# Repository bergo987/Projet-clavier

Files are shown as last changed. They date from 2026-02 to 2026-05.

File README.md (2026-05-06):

# Clavier mécanique programmable – Projet EEL8-PROJ1 [CLA]

## 📌 Présentation du projet

Ce dépôt contient le travail réalisé dans le cadre du **projet thématique EEL8-PROJ1 (2025–2026)** à l’ENSEIRB-MATMECA.  
L’objectif du projet est de **concevoir et réaliser un clavier mécanique programmable** basé sur un **microcontrôleur**, communiquant avec un ordinateur via le standard **USB HID**.

Contrairement aux solutions existantes « clé en main » (ex. QMK), ce projet privilégie le **développement d’un firmware personnalisé**, afin de maîtriser les aspects bas niveau du système embarqué. Nous avons programmé la carte Raspberry Pi pico directement (en baremetal).

---

## 🎯 Objectifs

- Concevoir un **clavier mécanique compact et minimaliste** ✅
- Implémenter un **scan matriciel des touches** ✅
- Gérer le **n-key rollover** et l’**anti-ghosting**
- Développer un **firmware bas niveau** sur microcontrôleur ✅
- Communiquer avec un ordinateur via **USB HID** ✅
- Ajouter une **interface utilisateur** :
  - LEDs sous les touches ✅
  - Gestion de profils ✅
  - Écran OLED pour l’affichage du profil actif et de la mesure de courant ✅ 🚧

---

## 🧠 Fonctionnalités principales

- Lecture matricielle des touches
- Détection fiable des appuis multiples
- Gestion de plusieurs profils clavier
- Éclairage LED configurable selon le profil
- Affichage des informations sur écran OLED
- Communication USB HID avec l’ordinateur

---

## 🛠️ Technologies utilisées

- **Microcontrôleur** : Raspberry Pi Pico (RP2040) [git ici](https://github.com/raspberrypi/pico-sdk)
- **Langage** : C / C++ (firmware embarqué)
- **Communication** : USB HID
- **Conception électronique** : PCB personnalisé
- **Interface utilisateur** :
  - LEDs adressables
  - Écran OLED
  - Potentiomètre (Seul le bouton fonctionne)

---

## 🧩 Organisation du projet

```text
├── firmware/        # Code source du firmware
├── hardware/        # Fichiers 3D et fichiers sources KIKAD
├── docs/            # Documentation technique
├── images/          # Illustrations et photos du projet
└── README.md
```

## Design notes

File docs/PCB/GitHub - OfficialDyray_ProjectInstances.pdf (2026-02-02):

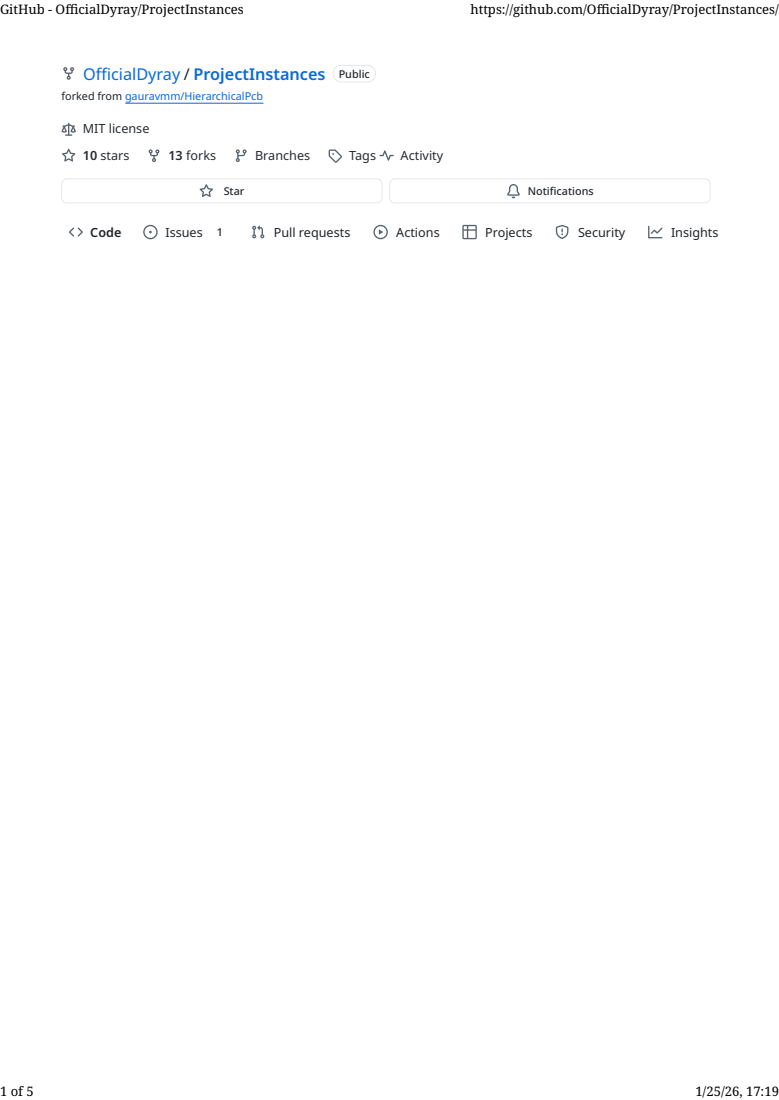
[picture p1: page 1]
10 stars; 13 forks; Branches; Tags; Activity; Star; Notifications; Code; Issues; Pull requests; Actions; Projects; Security; Insights; GitHub - OfficialDyray/ProjectInstances; https://github.com/OfficialDyray/ProjectInstances/

OfficialDyray (https://github.com/OfficialDyray) / ProjectInstances (https://github.com/OfficialDyray/ProjectInstances) Public
forked from gauravmm/HierarchicalPcb (https://github.com/gauravmm/HierarchicalPcb)
MIT license (https://github.com/OfficialDyray/ProjectInstances/blob/schParser/LICENSE)

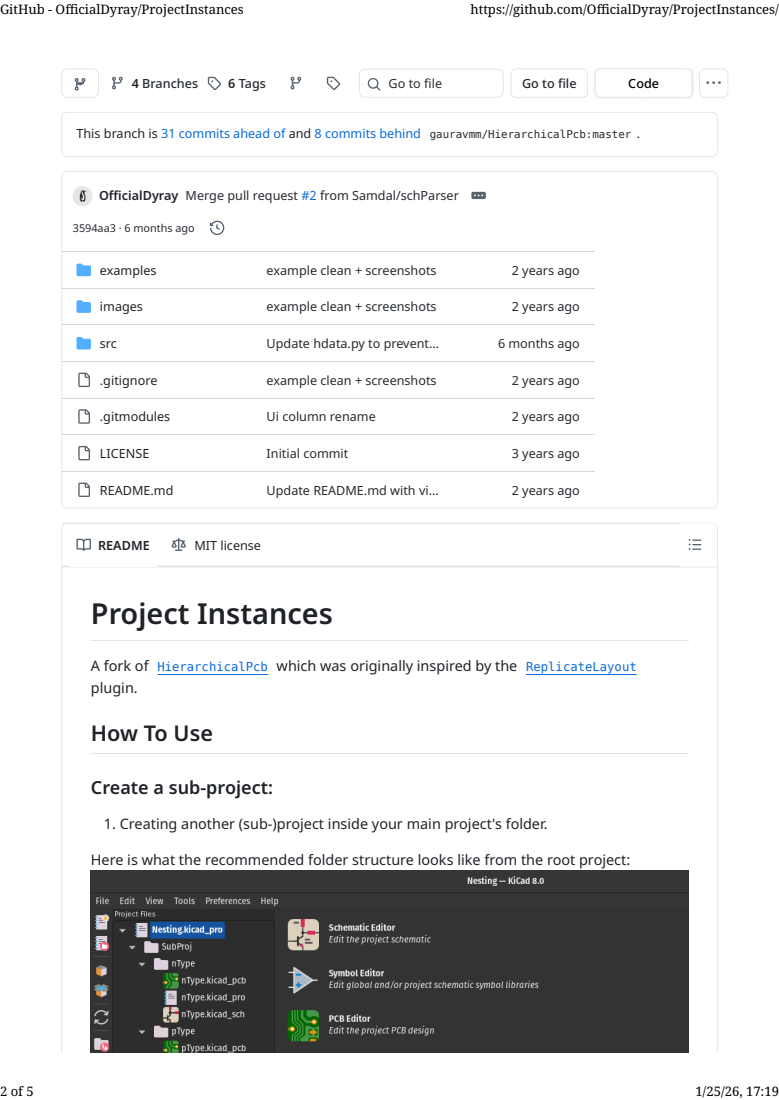
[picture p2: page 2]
4 Branches; 6 Tags; Go to file; Code; This branch is 31 commits ahead of and 8 commits behind; gauravmm/HierarchicalPcb:master; 3594aa3 · 6 months ago; examples; example clean + screenshots; 2 years ago; images; src; Update hdata.py to prevent…; 6 months ago; .gitignore; .gitmodules; Ui column rename; LICENSE; Initial commit; 3 years ago; README.md; Update README.md with vi…; A fork of; HierarchicalPcb; which was originally inspired by the; ReplicateLayout; plugin.; Project Instances; README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

OfficialDyray (https://github.com/OfficialDyray/ProjectInstances/commits?author=OfficialDyray) Merge pull request (https://github.com/OfficialDyray/ProjectInstances/commit/3594aa3a2f53df845697bdb446bcac1a703b43f1) #2 (https://github.com/OfficialDyray/ProjectInstances/pull/2) from Samdal/schParser

How To Use

Create a sub-project:
1. Creating another (sub-)project inside your main project's folder.
Here is what the recommended folder structure looks like from the root project:

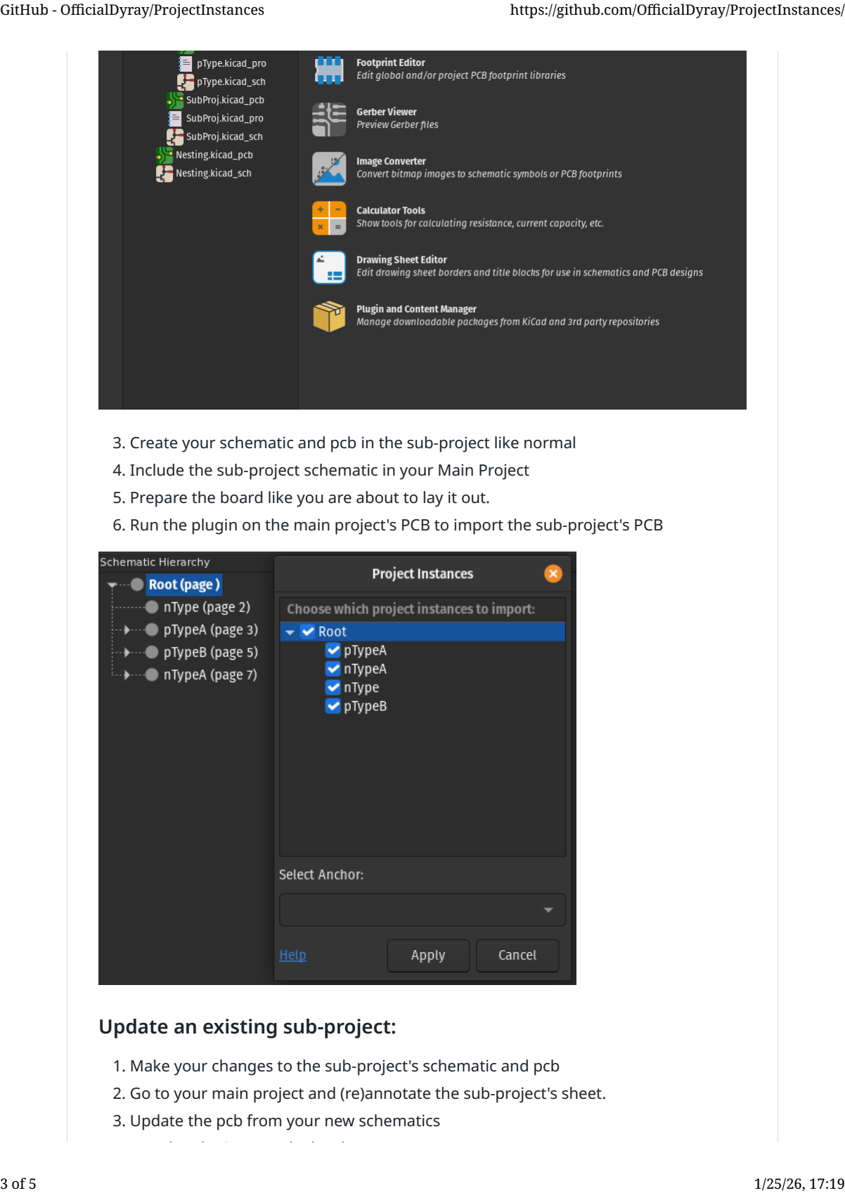
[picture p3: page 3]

3. Create your schematic and pcb in the sub-project like normal
4. Include the sub-project schematic in your Main Project
5. Prepare the board like you are about to lay it out.
6. Run the plugin on the main project's PCB to import the sub-project's PCB
1. Make your changes to the sub-project's schematic and pcb
2. Go to your main project and (re)annotate the sub-project's sheet.
3. Update the pcb from your new schematics

Update an existing sub-project:

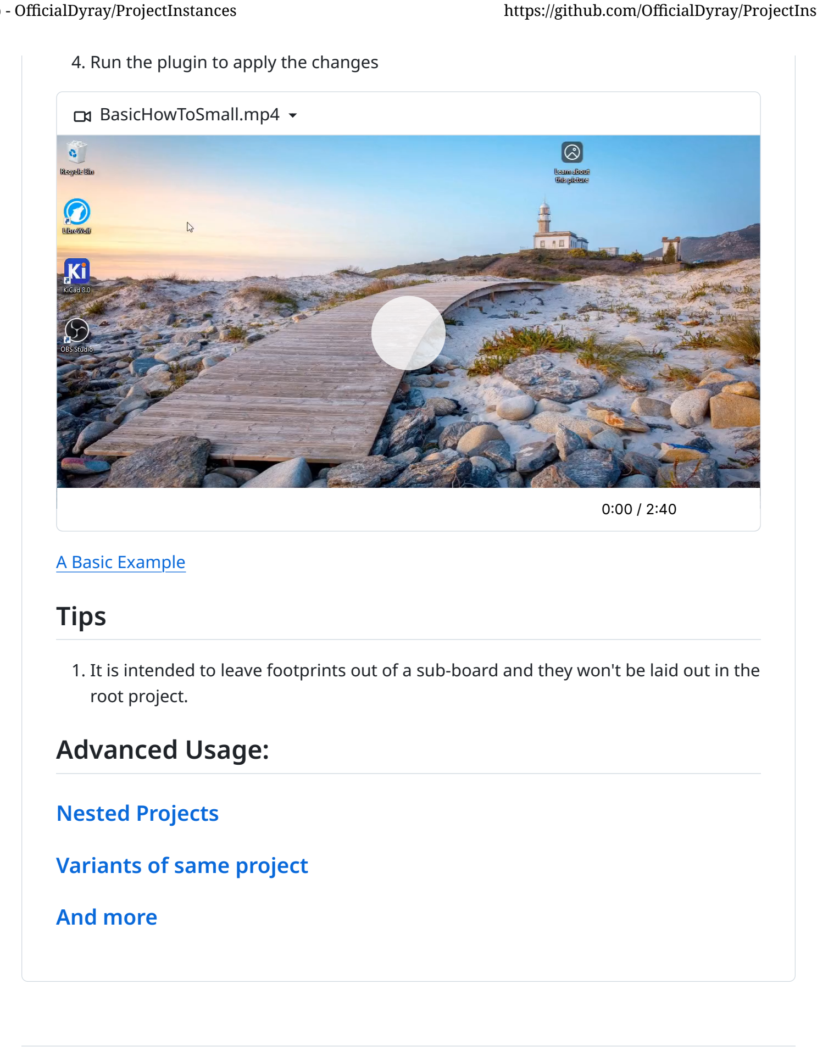
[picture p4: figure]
4. Run the plugin to apply the changes; BasicHowToSmall.mp4; A Basic Example; root project.; Tips; Advanced Usage:; Nested Projects; Variants of same project; And more

1. It is intended to leave footprints out of a sub-board and they won't be laid out in the

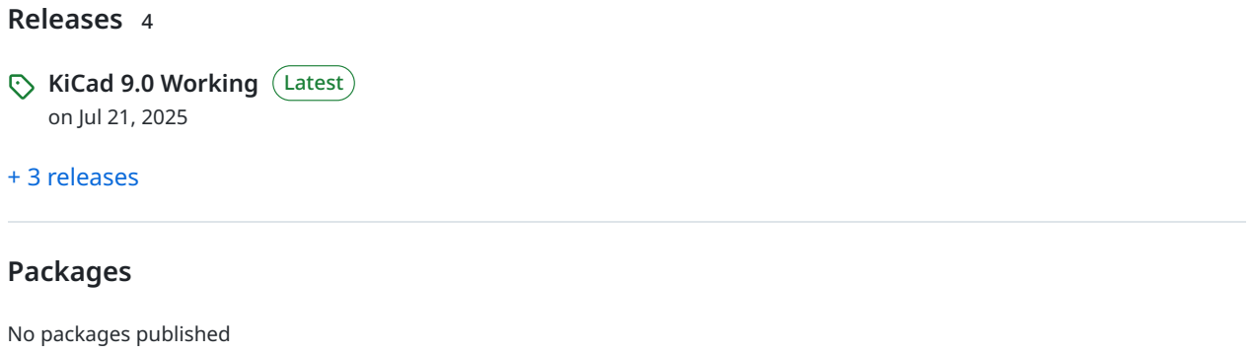
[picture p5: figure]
Releases; KiCad 9.0 Working Latest on Jul 21, 2025; + 3 releases; Packages; No packages published

Languages

Python 100.0%

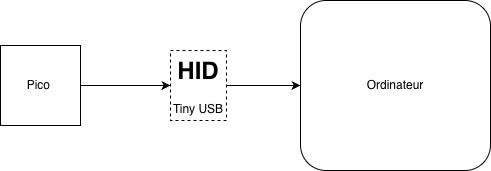
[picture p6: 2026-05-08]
firmware/Hid.png

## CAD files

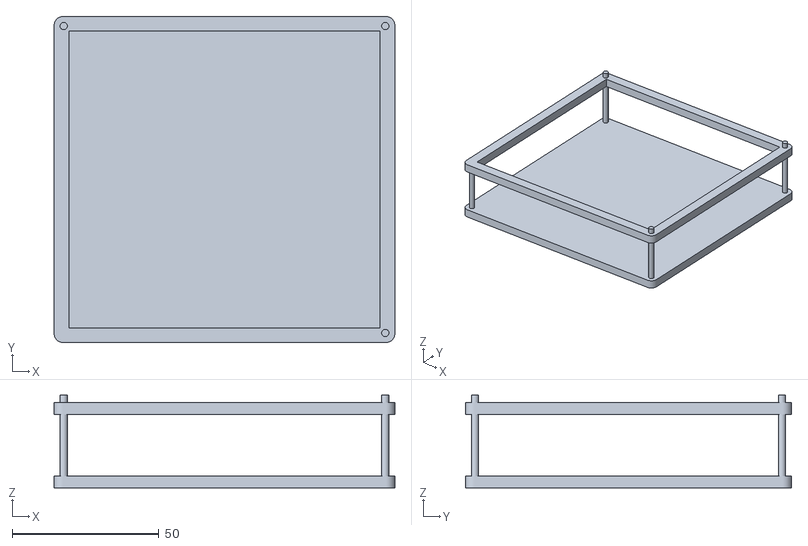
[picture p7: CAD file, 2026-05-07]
hardware/Case.stl
116.0 x 111.0 x 31.5

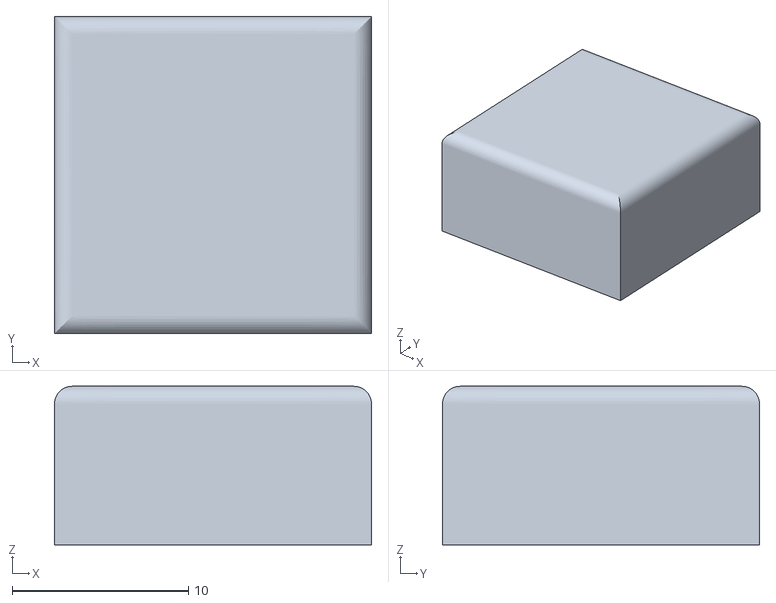
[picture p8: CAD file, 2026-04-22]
hardware/Keycap.stl
18.0 x 18.0 x 9.00

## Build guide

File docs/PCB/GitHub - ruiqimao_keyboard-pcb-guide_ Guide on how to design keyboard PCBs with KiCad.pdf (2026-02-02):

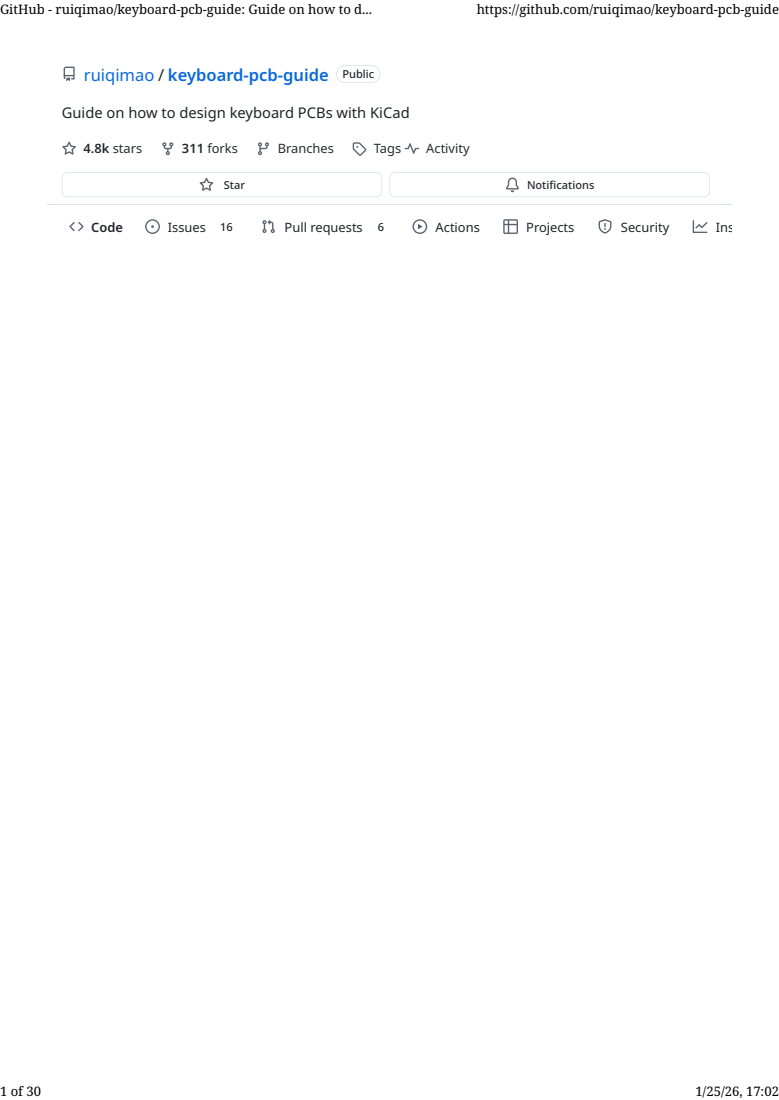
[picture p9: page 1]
4.8k stars; 311 forks; Branches; Tags; Activity; Star; Notifications; Code; Issues; Pull requests; Actions; Projects; Security; Insights; GitHub - ruiqimao/keyboard-pcb-guide: Guide on how to d...; https://github.com/ruiqimao/keyboard-pcb-guide

ruiqimao (https://github.com/ruiqimao) / keyboard-pcb-guide (https://github.com/ruiqimao/keyboard-pcb-guide) Public

Guide on how to design keyboard PCBs with KiCad

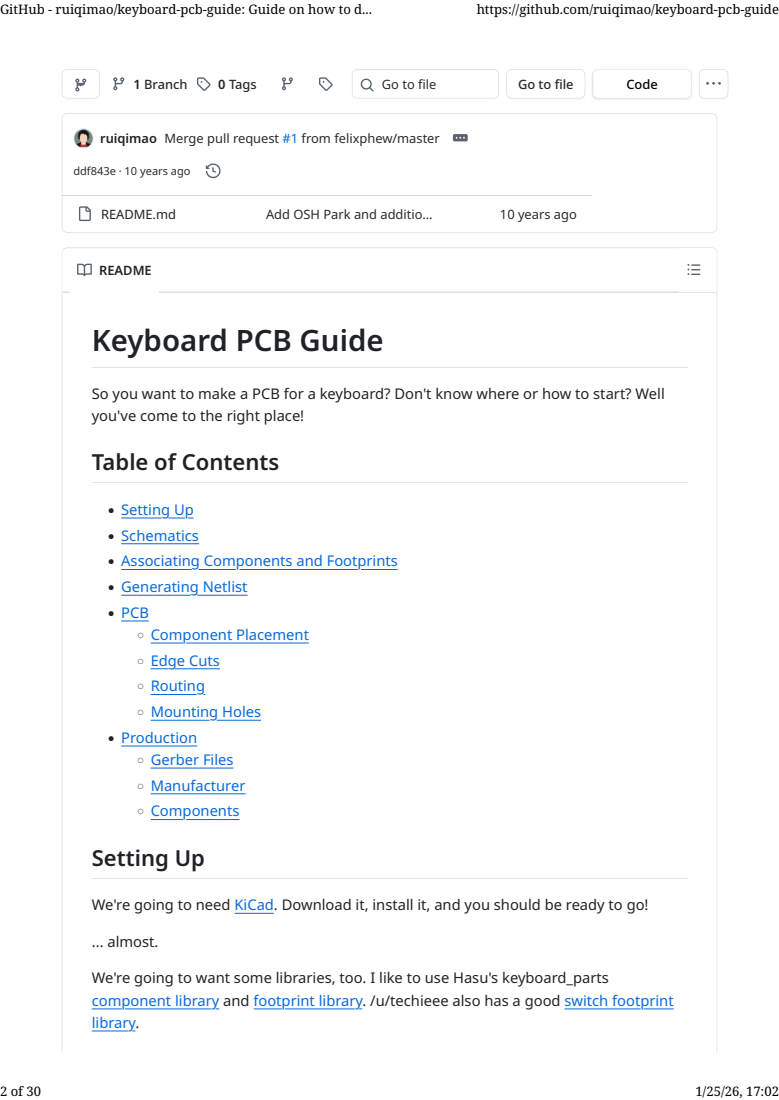
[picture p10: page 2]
1 Branch; 0 Tags; Go to file; Code; ddf843e · 10 years ago; README.md; Add OSH Park and additio…; 10 years ago; Setting Up; README

ruiqimao (https://github.com/ruiqimao/keyboard-pcb-guide/commits?author=ruiqimao) Merge pull request (https://github.com/ruiqimao/keyboard-pcb-guide/commit/ddf843ee5a5d36edd875370d22974dc7cd6f62e4) #1 (https://github.com/ruiqimao/keyboard-pcb-guide/pull/1) from felixphew/master

Keyboard PCB Guide

So you want to make a PCB for a keyboard? Don't know where or how to start? Well
you've come to the right place!

Table of Contents

• Setting Up (https://github.com/ruiqimao/keyboard-pcb-guide#setting-up)
• Schematics (https://github.com/ruiqimao/keyboard-pcb-guide#schematics)
• Associating Components and Footprints (https://github.com/ruiqimao/keyboard-pcb-guide#associating-components-and-footprints)
• Generating Netlist (https://github.com/ruiqimao/keyboard-pcb-guide#generating-netlist)
• PCB (https://github.com/ruiqimao/keyboard-pcb-guide#pcb)
◦ Component Placement (https://github.com/ruiqimao/keyboard-pcb-guide#component-placement)
◦ Edge Cuts (https://github.com/ruiqimao/keyboard-pcb-guide#edge-cuts)
◦ Routing (https://github.com/ruiqimao/keyboard-pcb-guide#routing)
◦ Mounting Holes (https://github.com/ruiqimao/keyboard-pcb-guide#mounting-holes)
• Production (https://github.com/ruiqimao/keyboard-pcb-guide#production)
◦ Gerber Files (https://github.com/ruiqimao/keyboard-pcb-guide#gerber-files)
◦ Manufacturer (https://github.com/ruiqimao/keyboard-pcb-guide#manufacturer)
◦ Components (https://github.com/ruiqimao/keyboard-pcb-guide#components)

We're going to need KiCad. (http://kicad-pcb.org/) Download it, install it, and you should be ready to go!
... almost.
We're going to want some libraries, too. I like to use Hasu's keyboard_parts
component library (https://github.com/tmk/kicad_lib_tmk) and footprint library. (https://github.com/tmk/keyboard_parts.pretty) /u/techieee also has a good switch footprint
library. (https://github.com/egladman/keebs.pretty)

Download all of these and we should be good to go!

Make sure you also have the official KiCad libraries as well. Those should be included with your KiCad installation.

Start up KiCad and create a new project (File > New Project > New Project). Name the project whatever you want. For the purposes of this guide, I'll be calling it "example". Very creative, I know.

We'll start by designing our schematics. Double click on your | .sch | file and you
should be greeted with an empty schematic sheet:

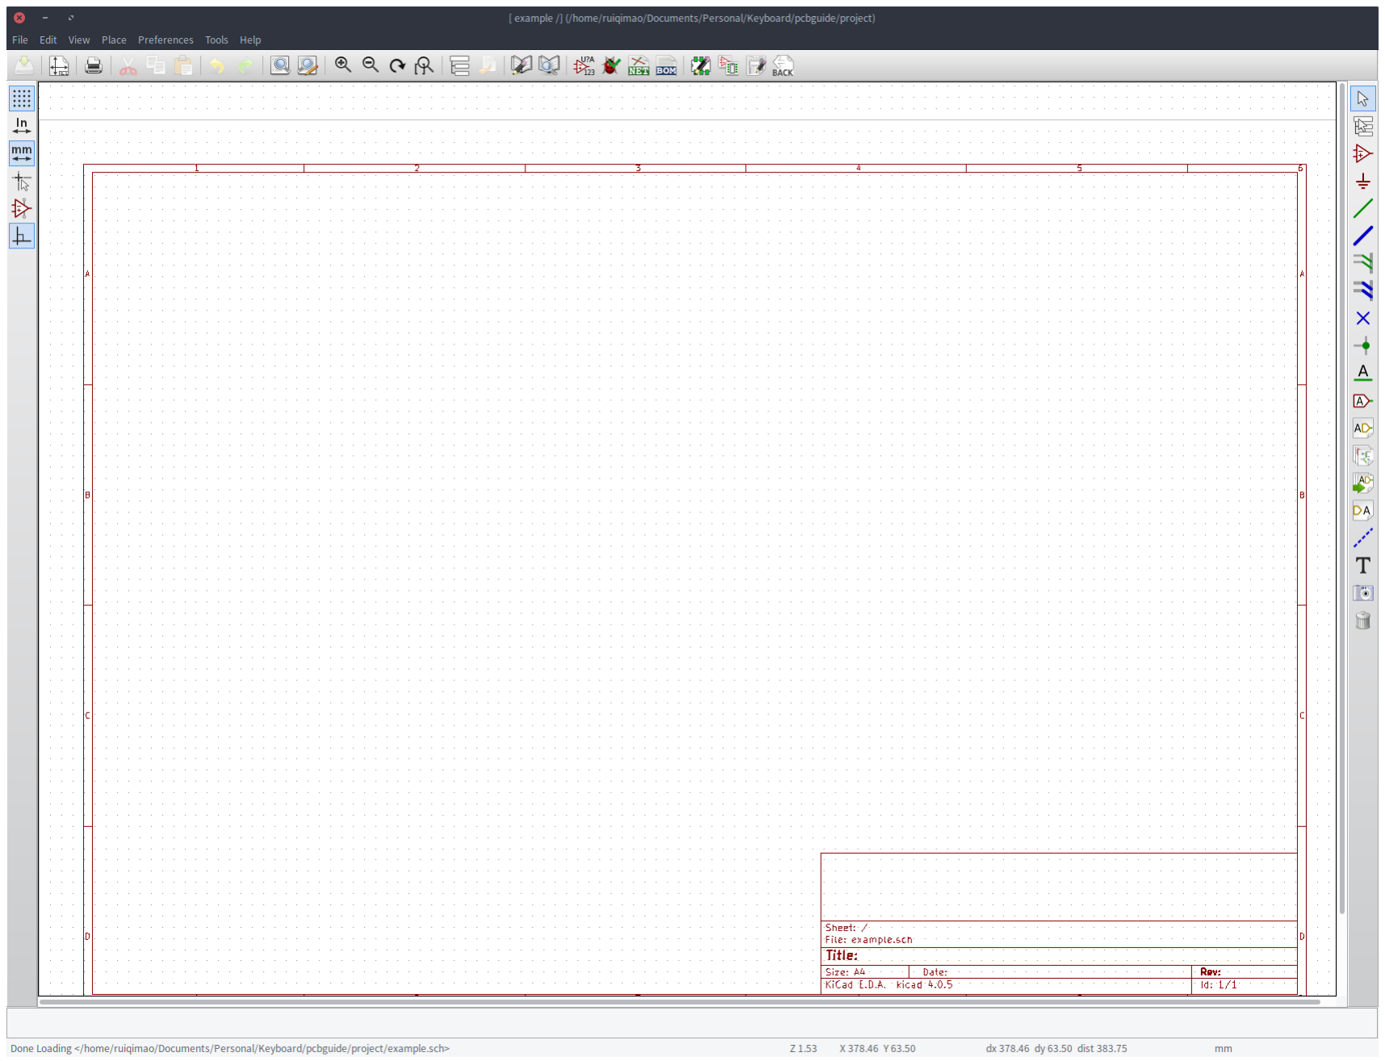
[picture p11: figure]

Let's add our component library. At the top of the window, click on Preferences >
Component Libraries. Then, click on "Add" and find the | keyboard_parts.lib | file from
Hasu's library. Scroll down to the bottom of the component library list and find the library you just added. We want to move that to the top of the list, so your list should look like this:

Schematics

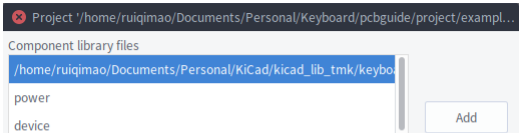
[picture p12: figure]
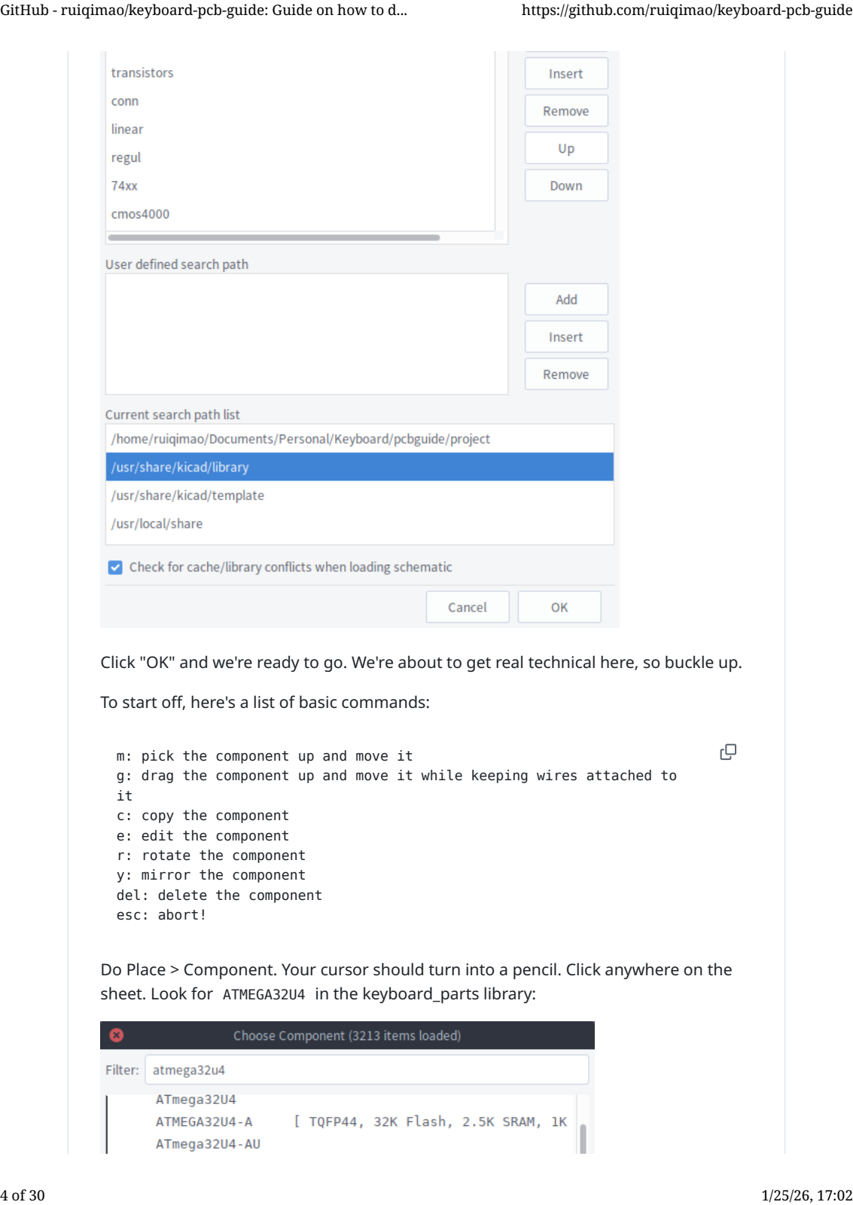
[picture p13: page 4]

Click "OK" and we're ready to go. We're about to get real technical here, so buckle up.

To start off, here's a list of basic commands:

Do Place > Component. Your cursor should turn into a pencil. Click anywhere on the
sheet. Look for | ATMEGA32U4 | in the keyboard_parts library:

m: pick the component up and move it
g: drag the component up and move it while keeping wires attached to it
c: copy the component
e: edit the component
r: rotate the component
y: mirror the component
del: delete the component
esc: abort!

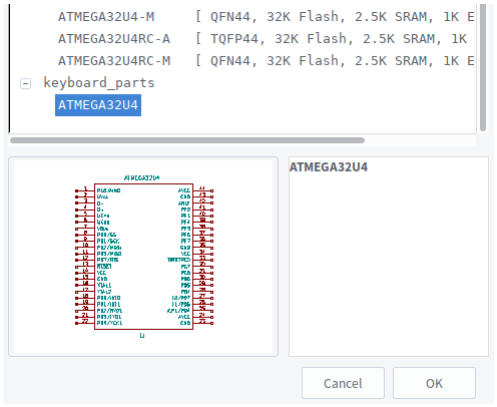
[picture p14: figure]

Click OK, then click on the schematic sheet again to place the component. This is our controller. Edit the component and change the reference from "U?" to "U1". This is the unique name that we're going to use to refer to this particular component.

The next part we'll want to place is the crystal, which is the part that tells the
controller how fast to run. Look for the | XTAL_GND | component and place it next to the
controller. Change the reference to X1.

Next, we're going to want to add 2 decoupling capacitors ( C_SMALL ). These capacitors will basically help prevent the signal to the controller from accumulating too much noise. There's a formula for determining the capacitance you need for these capacitors, but for now, we'll use a crystal with 18pF load capacitance, so these decoupling capacitors will be 22pF. Name them C1 and C2, and change their values to 22p. Also add a GND symbol to represent ground, and connect everything using the wire tool (green line on the right) like so:

Next, we'll add decoupling capacitors for VCC, our power source. We will generally want one 0.1uF capacitor for each VCC/AVCC on the controller and one 4.7uF capacitor for UVcc. In our case, we want 4 0.1uF capacitors and 1 4.7uF capacitor, like so:

Let's hook up a reset switch. For this, you'll want a switch ( SW_PUSH | ) named SW1 and
a 10k resistor for pullup ( R | ) named R1. If you want to know why we want a pullup
resistor and what a pullup resistor even means, here (https://learn.sparkfun.com/tutorials/pull-up-resistors) is a good explanation from Sparkfun. But for now, here's how it should be hooked up:

Now let's put a 10k resistor named R2 on HWB/PE2 pin and connect it to ground. We want a resistor here because it tells the microcontroller that when we press the reset button, we want to go into the bootloader so that we can flash a new layout onto it!

Next, let's add our USB port. Add the | USB_mini_micro_B | component from the

keyboard_parts library and call it J1. Connect VUSB to VCC and Uvcc, and put two 22 ohm resistors R3 and R4 between the D- and D+ connections. Connect GND and SHIELD together and connect them to ground. And lastly, put a 1uF capacitor C8 between UCap and GND:

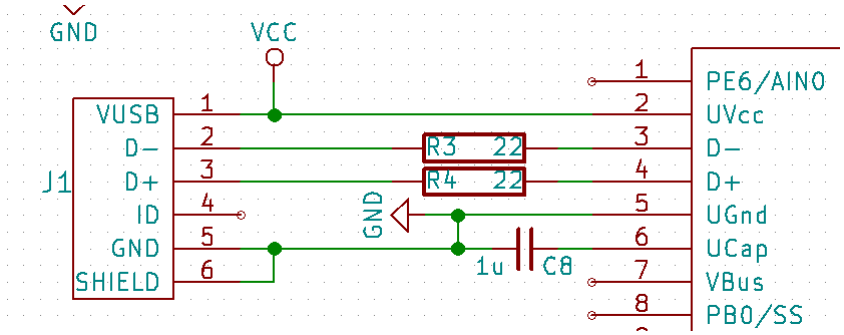
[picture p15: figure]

Let's connect all the VCC connections together and all the GND connections together. Normally, you would place a capacitor between AVCC and VCC if you were using the built-in ADC (analog to digital converter), but we don't care about that for a keyboard, so just directly connect them. Here's what everything look like at this point:

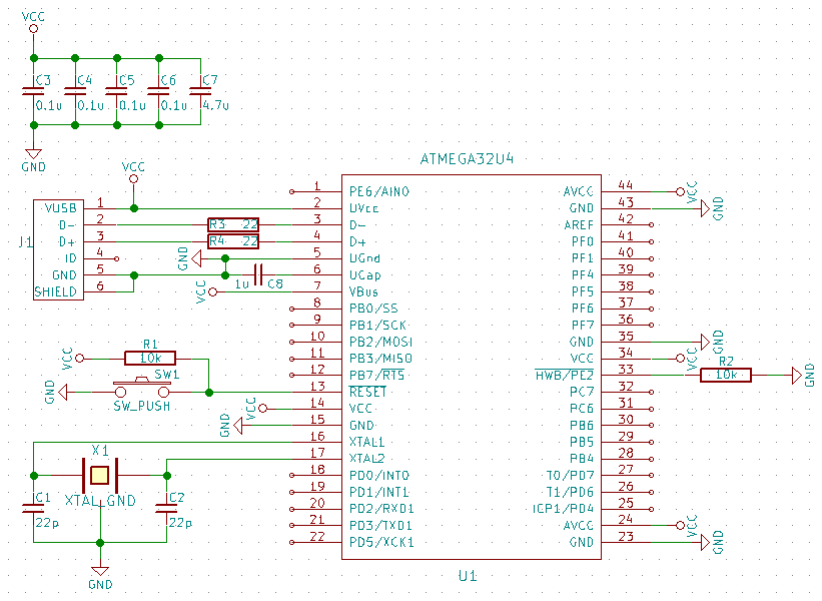
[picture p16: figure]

Now let's build our switch matrix. For the purposes of this guide, we're simply making
a nice and easy 2x2 matrix. We're going to want to use the | KEYSW | and | D | components
for our switch and diode components, respectively. Just connect them like you would a handwired board, and don't forget to name them. K1 should correspond to D1, K2 should correspond to D2, and so on:

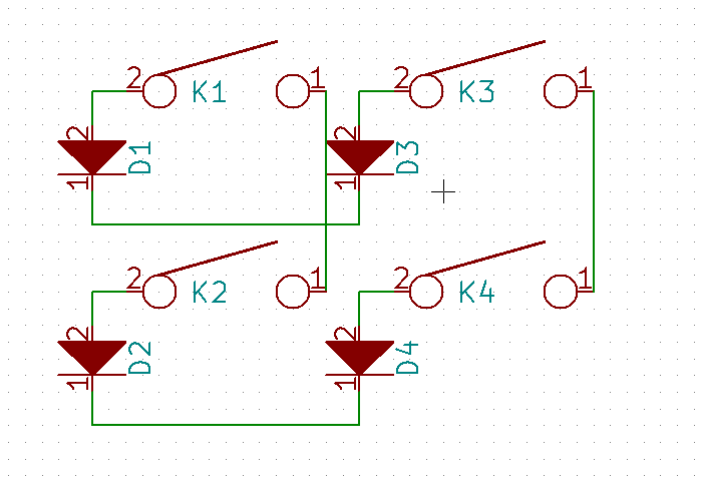
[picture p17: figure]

Now we want to connect this matrix to the controller. We'll use labels for ease (A with a green line underneath on the right). For our example board, we'll use PF0 for row0, PF1 for row1, PF4 for col0, and PF5 for col1:

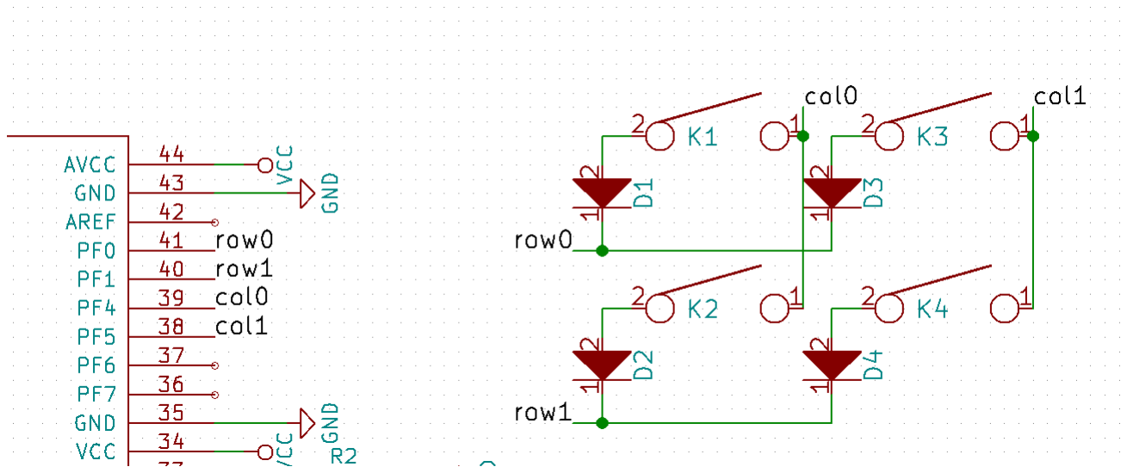
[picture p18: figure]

Finally, let's label all the unused pins as not connected. Use the no connect tool (blue X on the right) and click on all the unconnected pins on the controller and the ID pin on the USB port. This is also a good chance to make sure you didn't miss any VCC or GND pins earlier! Our final schematic should look like this:

We have to tell KiCad what each of these components means. Click on the icon for CvPcb at the top:

If this is your first time running CvPcb, we're going to need to add the footprint libraries we downloaded earlier. Click Preferences > Footprint Libraries, and in the window that shows up, use the "Append with Wizard" button to add the "keebs.pretty" and "keyboard_parts.pretty" folders that we downloaded earlier. You may also need to manually add the built-in KiCad libraries. Your list of libraries should look something like this now:

Associating Components and Footprints

We're going to assume that all of our capacitors and resistors are 0805 imperial size. Our ATmega32U4 is going to be in a TQFN package. We're going to use the very handy hybrid through-hole and surface mount footprint from Hasu's library for our diodes. Switches are going to be /u/techieee's 1u switch footprint. The crystal will be an FA-238 series crystal. The reset button will be a TL3442 series button, and the USB mini B port will be a Hirose 5S8 connector. For each component, go through the list of footprints and double click on one to associate it with the currently selected component. Here's what all the associations should end up looking like:

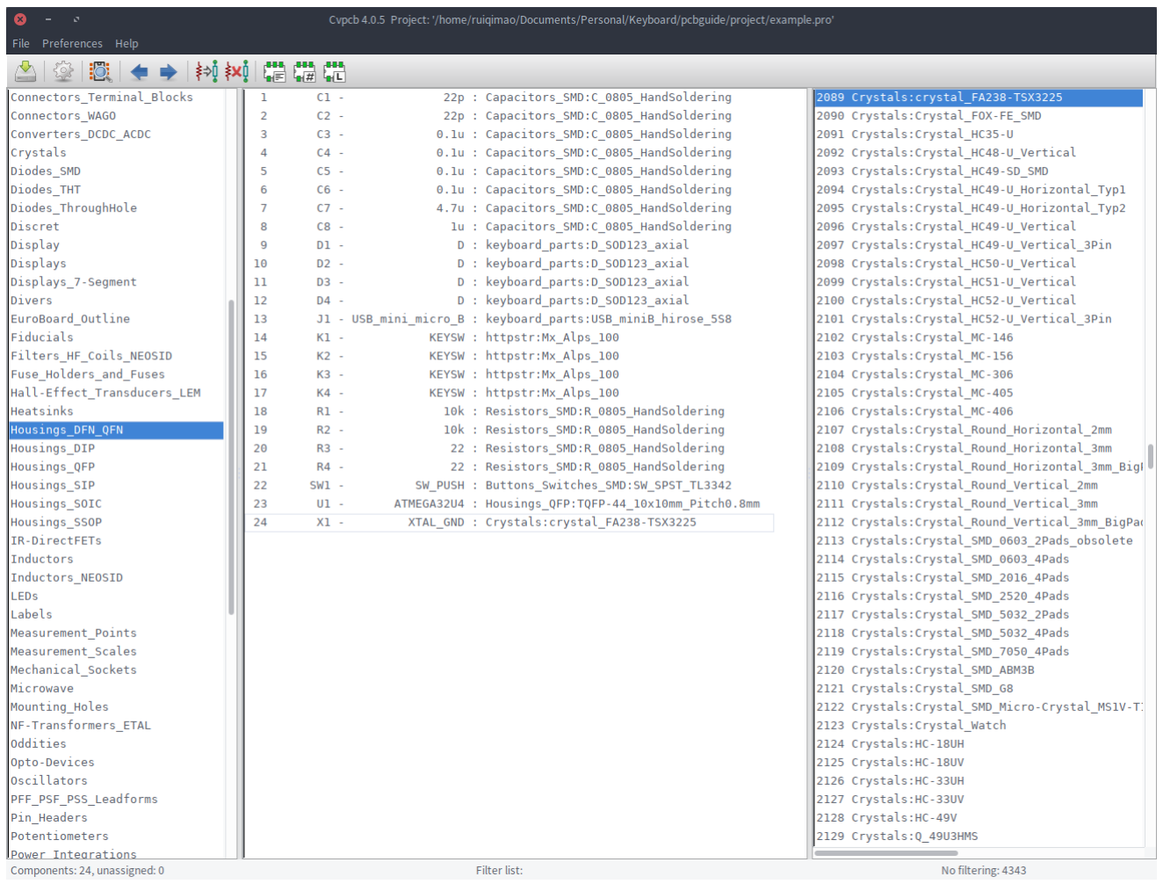
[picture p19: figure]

Save the assocations and close the window.

Now we want to generate the netlist, which is essentially a list of connections in our schematic. Click on the netlist button:

In the dialog that opens, simply click "Generate". Use the default netlist name in the save dialog. If everything was laid out and named properly, KiCad should not ask you

Generating Netlist about annotations. If so, click "Cancel" and double check all of your references then try again.

Now we get to create our PCB! Save and close out of the schematic editor. Then, go back to your project and open your ".kicad_pcb" file. You should be greeted by a blank PCB editor:

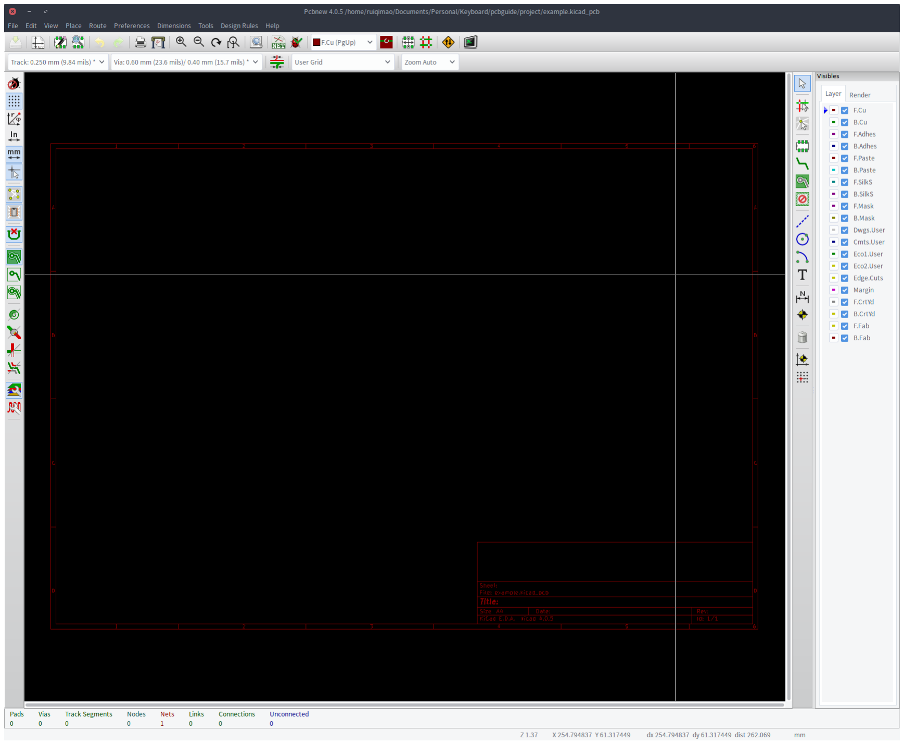
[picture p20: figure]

The first thing we're going to do is double check that all of our footprints are still here. Go to Preferences > Footprint Libraries Manager and make sure that all the footprint libraries you imported earlier are still there. If not, then simply import them again.

Next, we're going to set our grid. Click on Dimensions > Grid, and set Units to Inches and Size X and Size Y both to 0.09375, like so:

PCB

Then, we want to tell the PCB editor to use our user-defined grid. Change the grid option at the top to "User Grid".

The easiest way to get all our footprints onto the board is to read the netlist we generated earlier. Click on the netlist button, which should look the same as before, and simply click on "Read Current Netlist". A bunch of messages should show up, and the dialog should look something like:

Now, click "Close". You'll notice that there are now a bunch of footprints in the middle of the screen all stacked on top of each other:

Before we separate them, let's hide the ratsnest, which is essentially the lines that detail the electrical connections in the board. Go to the "Render" tab on the right and uncheck "Ratsnest", like so:

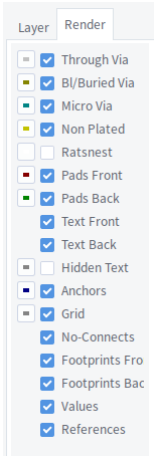
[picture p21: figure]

Here are some useful commands for the PCB editor:

Let's separate our footprints and put them on the correct side of the PCB. The only footprints that will be on the "front" of the PCB will be the switch footprints. Everything else will be on the "back" of the PCB, so make sure everything but the switches are flipped:

m: move the footprint
g: drag the footprint while keeping connectivity e: edit the footprint
r: rotate the footprint
f: flip the footprint
del: delete the footprint
esc: abort!

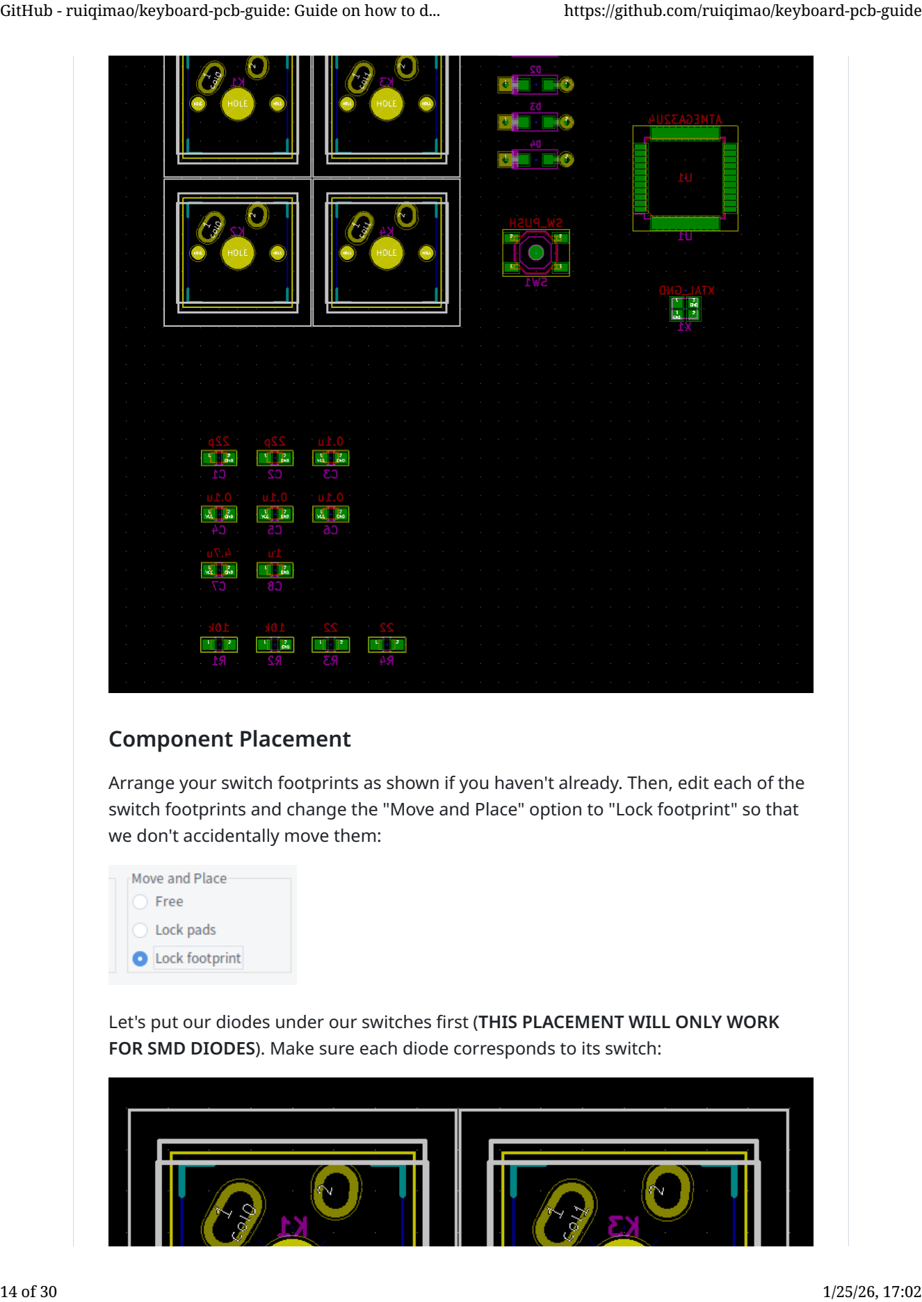
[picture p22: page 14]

Arrange your switch footprints as shown if you haven't already. Then, edit each of the switch footprints and change the "Move and Place" option to "Lock footprint" so that we don't accidentally move them:

Let's put our diodes under our switches first (THIS PLACEMENT WILL ONLY WORK FOR SMD DIODES). Make sure each diode corresponds to its switch:

Component Placement

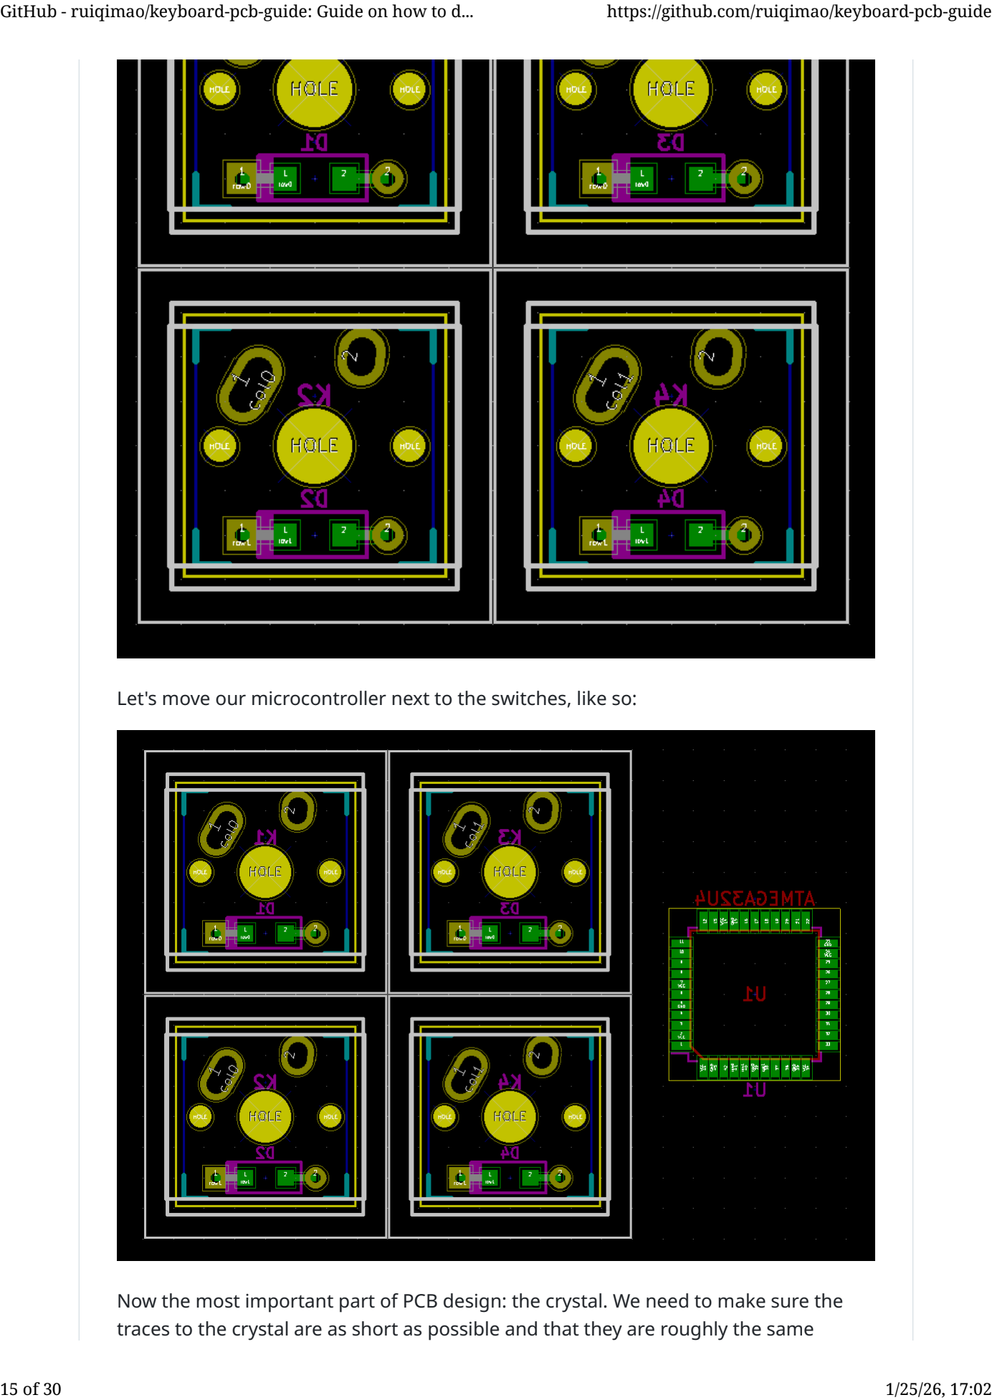
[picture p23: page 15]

Let's move our microcontroller next to the switches, like so:

Now the most important part of PCB design: the crystal. We need to make sure the traces to the crystal are as short as possible and that they are roughly the same

length. An easy way to tell what pads are supposed to connect to what pads is to use the "highlight net" tool on the right. You use the tool and simply click on a pad, and it and the pads it connects to are highlighted. For this example, I put the crystal above the microcontroller and rotated it by 45 degrees:

Then place the 2 decoupling capacitors next to their respective pads:

You don't need to worry about connecting ground to any other grounds, since we will be putting a ground plane under all the components. More on that later.

Next, we want to place the decoupling capacitors for VCC. Place a 0.1uF capacitor next to each VCC and AVCC and the 4.7uF capacitor next to UVCC. At this point, I discovered that the microcontroller was a little too close to the switches, so I move it out a little bit:

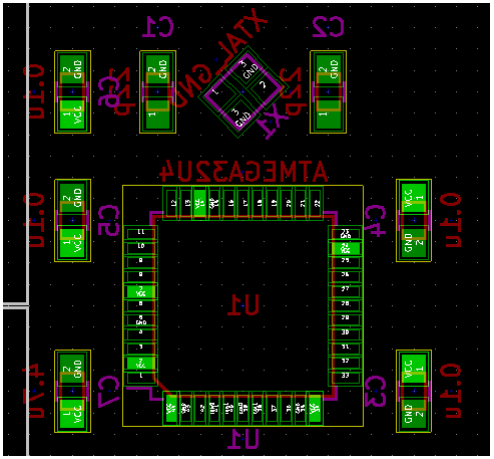
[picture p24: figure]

Let's put our last capacitor on, which will fit nicely between C5 and C7:

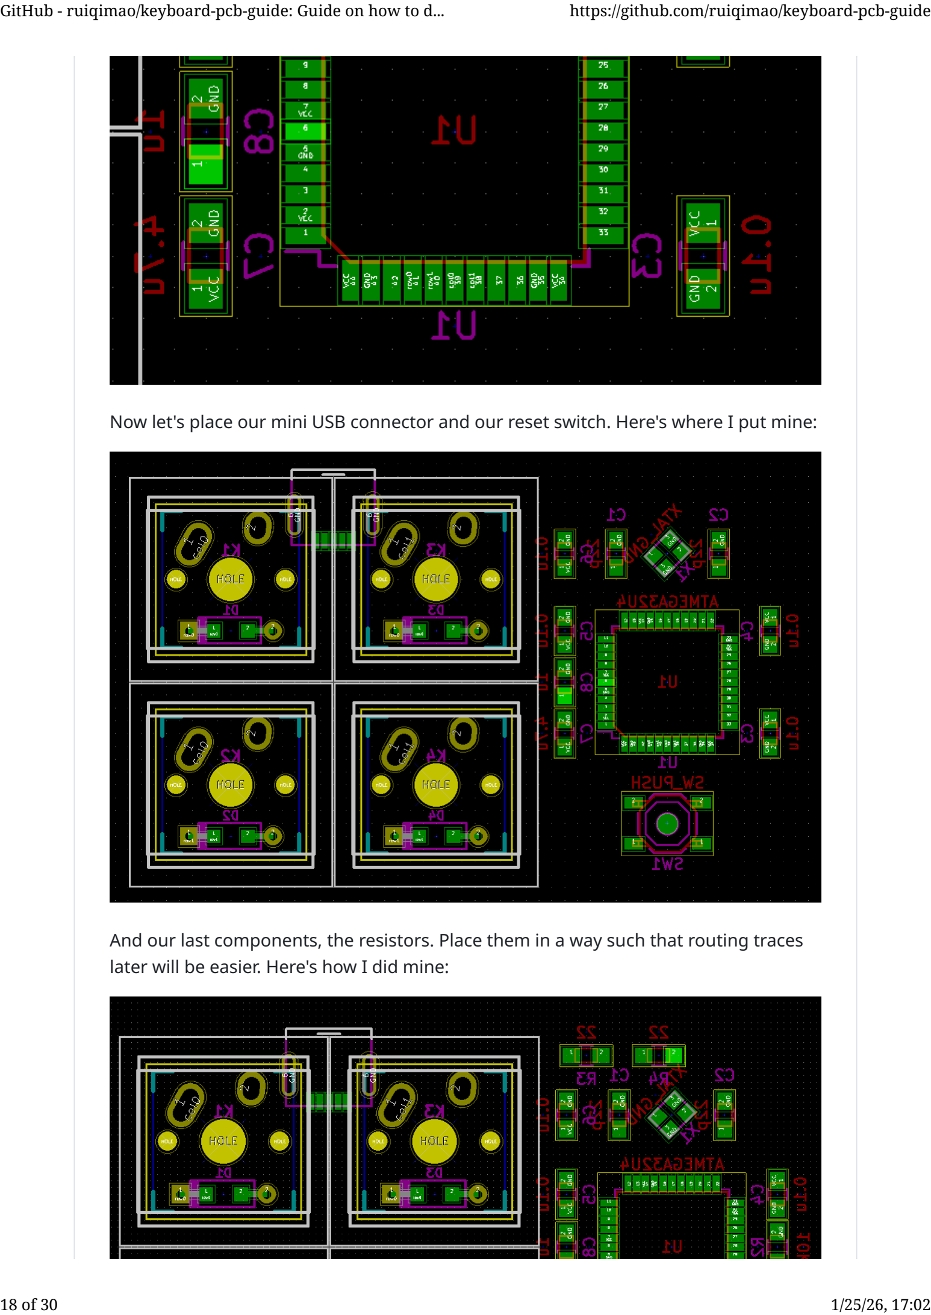
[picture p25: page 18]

Now let's place our mini USB connector and our reset switch. Here's where I put mine:

And our last components, the resistors. Place them in a way such that routing traces later will be easier. Here's how I did mine:

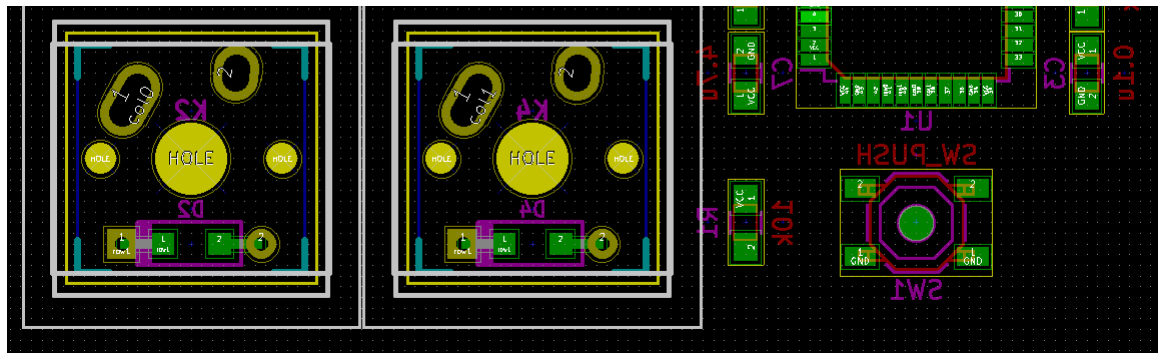
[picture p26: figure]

Note that at this point, my grid sizes are at 0.0234375" in each dimension to allow for finer positioning.

Now let's draw out the outline for our board! Go to the "Layer" tab on the right and click next to "Edge.Cuts" to move the blue arrow down to it, effectively selecting it as the layer we're going to draw on:

Use the drawing tools on the right to draw an outline for the PCB:

Edge Cuts

Here's how I cut mine:

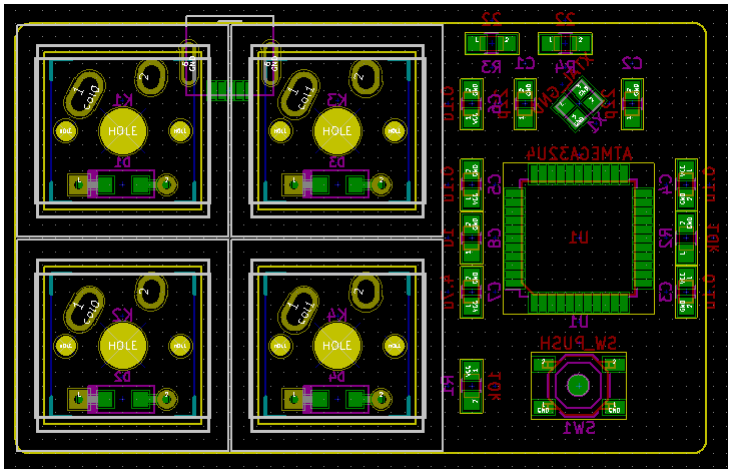
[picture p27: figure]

We want to put a ground plane in the PCB. Essentially, a ground plane is just one big chunk of copper that's connected to ground on both sides of the PCB. It's useful when we have a lot of components that are connected to ground, like in our PCB. To do this, we want to use the zone tool:

Make sure the blue arrow is back on F.Cu in the Layers tab. Then, select the zone tool and click on one of the corners of the edge cuts. A dialog will pop up asking you which net the zone should be associated with. Select GND and hit "OK":

Ground Plane

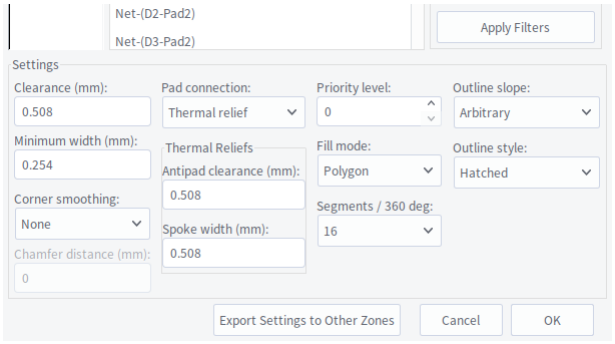
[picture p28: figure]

Now, draw a border where you put the edge cuts. When you get back to the starting point, double click. You will see a red hatch pattern around your PCB. Now right click on the edge of the zone and select Zones > Duplicate Zone onto Layer. The same dialog will pop up, but this time, select B.Cu on the left and hit "OK". Now your PCB will have both a red and green hatch pattern around it:

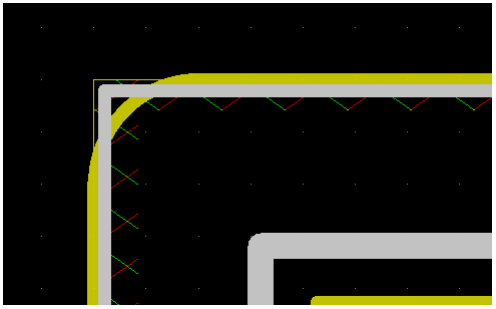
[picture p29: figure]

Now right click and select each zone, and for each zone, select Zone > Fill Zone. Make sure the option to show filled zones is selected on the left:

And your PCB should now look something like this:

Now choose the option to hide filled zones. We don't want them while routing.

Now we want to do some routing. To route, we want to use the "add tracks and vias" tool:

I would also recommend setting your grid size to 0.25mm for this part.

Let's get some terminology out of the way first:

- A trace is a physical electrical copper connection. Like a wire.
- A via is a hole that goes through both sides of the PCB. This is useful because when routing traces, we'll run into collisions where we can't route a trace through another. A via lets us hop to the other side of the PCB and continue the trace on the other side.
While routing, you can press | v | to switch layers and create a via.

Now that we've gotten that out of the way, let's set some ground rules. Well, one ground rule. Namely, no vias between the crystal and the controller. Vias can potentially lead to a small amount of capacitance that can actually affect our crystal operation, so that's a big no no.

Now let's start routing. The first thing you want to route is always the crystal and the decoupling capacitors next to it. Luckily for us, this is pretty simple. To get started, make sure you have the B.Cu layer selected, since that's where most of our components are. Here's how I did mine:

Routing

Next, let's route the VCC lines. Make sure you route the decoupling capacitors to their appropriate VCC pins on the microcontroller. And don't forget to route to the USB port!

Now let's route the UCap capacitor and the rest of the resistors. Keep in mind that a well designed PCB will also look aesthetically pleasing. Here's how I routed the remaining capacitor and the resistors:

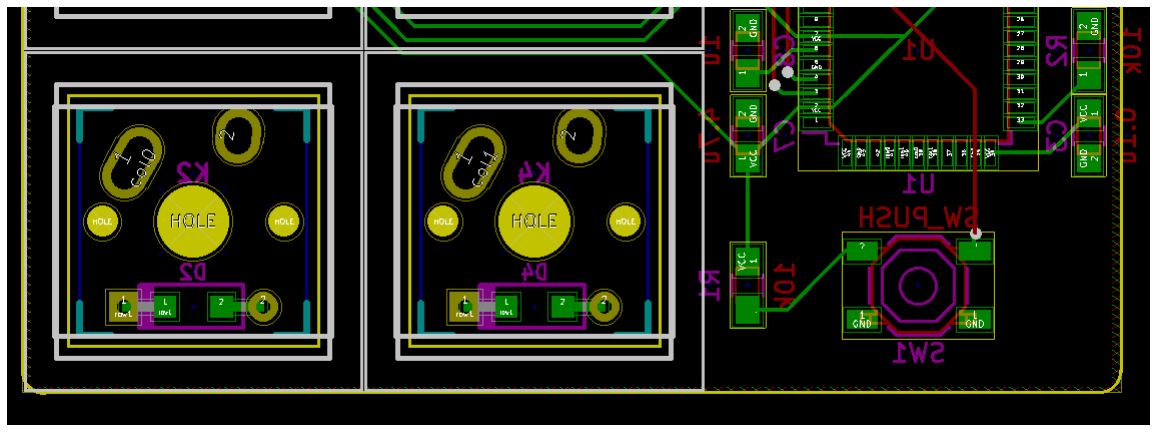
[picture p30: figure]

Note that I changed the routing of the switch to accommodate for the traces for the USB data resistors. You can also turn on the ratsnest in the Render tab on the right to check for any connections you have missed or any ground connections you may have accidentally broken while tracing routes. Ignore the traces that lead to the diodes and switches. We'll route those next. It turns out, I forgot to route all of the VCC pads together and broke a few ground connections. This is what my PCB looked like after fixing all the missed connections:

And now we'll route the diodes and switches. First, route the diodes and switches together before touching the controller:

And finally, we'll route the controller to the rows and columns:

Turn on your zones, fill in any missing ground planes, press | b | to update the zones,
and voila:

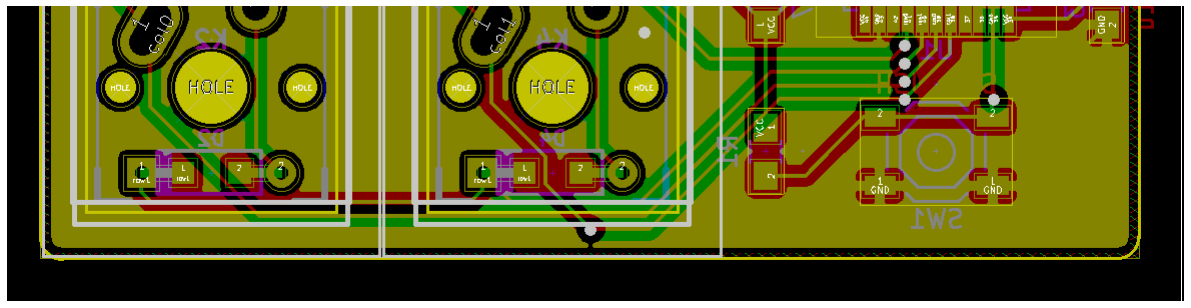
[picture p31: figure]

Double check that all connections have been made using the DRC (design rule check) tool:

Click "Start DRC" and make sure there are no problems. Then click "List Unconnected" and check for unconnected nets. If both sections are blank, then...

Your PCB is finished!

Go to View > 3D View and turn on Preference > Realistic Mode. Turn up all the settings you want, set your background color, and you'll have a nice render of your PCB! You can even select the Text tool and the B.SilkS layer to put your name on your PCB:

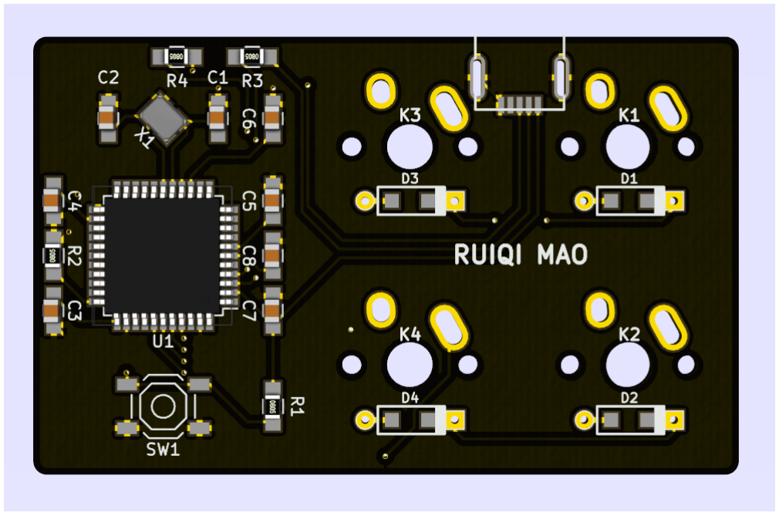
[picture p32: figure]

Now, with a normal PCB, you would want to add some mounting holes. The way you would add those would be by creating custom footprints with NPTH (non-plated through hole) pads and adding them to your PCB. This is out of scope for this guide, but this is something that is very simple to Google!

Mounting Holes

Now that you've finished designing your PCB, you want to get it made, right? Let's get you started on that.

First thing is to generate our "gerbers", which are essentially files that tell the PCB manufactuer what is on each layer. Click on the "plot" icon:

Specify a directory to put your gerber files into and make sure the F.Cu, B.Cu, B.Paste, F.Paste, B.SilkS, F.SilkS, B.Mask, F.Mask, and Edge.Cuts layers are selected. Check the "Use Protel filename extensions" option, and make sure the format is "4.6 (unit mm)":

Production

Gerber Files

Click on "Plot" to generate your files.

Then, click on "Generate Drill File". Set the output directory to be the same as before, set your drill units to "Inches", and your Drill Map File Format to "PostScript". Make sure "Mirror y axis" is unchecked, and then click "Drill File":

Now close the dialogs.

Put all the files you just generated into a zip file:

Upload your files onto http://www.gerber-viewer.com/ and make sure all the layers look good. If so, you're ready to send your PCB off to the manufacturer!

Now, there are a lot of options here. I've personally used PCBWay (http://www.pcbway.com/setinvite.aspx?inviteid=25678) (referral link) to great success, but there are plenty of other cheap PCB prototyping services, such as EasyEDA, (https://easyeda.com/) OSH Park (https://oshpark.com/) and DirtyPCBs. (http://dirtypcbs.com/store/pcbs)

All of these services simply involve choosing some options for how your PCBs will be manufactuered (default settings are fine for all of them), then uploading the zip file you just created. If you want to change the color of your PCB, then the option you will want to look for is "solder mask color". The color of the text on your PCB will be "silkscreen color".

Once you receive your PCBs, you can simply use some solder paste and a hot air rework station to put everything together! If you're unsure of how to do this, there are plenty of resources online that can teach you the basics of SMD soldering.

But where do you get the components from? I highly recommend DigiKey (http://www.digikey.com/) for components. Here's a list of all the components used in this guide:

- Microcontroller: https://www.digikey.com/product-detail/en/microchiptechnology/ATMEGA32U4-AUR/ATMEGA32U4-AURCT-ND/3440960 (https://www.digikey.com/product-detail/en/microchip-technology/ATMEGA32U4-AUR/ATMEGA32U4-AURCT-ND/3440960)
- Crystal: https://www.digikey.com/product-detail/en/epson/FA-238-16.0000MB-C3/SER3686CT-ND/2403459 (https://www.digikey.com/product-detail/en/epson/FA-238-16.0000MB-C3/SER3686CT-ND/2403459)
- 22pF Capacitors: https://www.digikey.com/product-detail/en/kemet/C0805C220J5GACTU/399-1113-1-ND/411388 (https://www.digikey.com/product-detail/en/kemet/C0805C220J5GACTU/399-1113-1-ND/411388)
- 0.1uF Capacitors: https://www.digikey.com/product-detail/en/yageo/CC0805ZRY5V9BB104/311-1361-1-ND/2103145 (https://www.digikey.com/product-detail/en/yageo/CC0805ZRY5V9BB104/311-1361-1-ND/2103145)
- 1uF Capacitors: https://www.digikey.com/product-detail/en/yageo/CC0805KKX7R7BB105/311-1365-1-ND/2103149 (https://www.digikey.com/product-detail/en/yageo/CC0805KKX7R7BB105/311-1365-1-ND/2103149)

Manufacturer

Components

- 4.7uF Capacitors: https://www.digikey.com/product-detail/en/murata-electronicsnorth-america/GRM21BR61E475KA12L/490-3335-1-ND/702876 (https://www.digikey.com/product-detail/en/murata-electronics-north-america/GRM21BR61E475KA12L/490-3335-1-ND/702876)
- 22 Ohm Resistors: https://www.digikey.com/product-detail/en/stackpoleelectronics-inc/RMCF0805JT22R0/RMCF0805JT22R0CT-ND/1942533 (https://www.digikey.com/product-detail/en/stackpole-electronics-inc/RMCF0805JT22R0/RMCF0805JT22R0CT-ND/1942533)
- 10k Ohm Resistors: https://www.digikey.com/product-detail/en/stackpoleelectronics-inc/RMCF0805JT10K0/RMCF0805JT10K0CT-ND/1942577 (https://www.digikey.com/product-detail/en/stackpole-electronics-inc/RMCF0805JT10K0/RMCF0805JT10K0CT-ND/1942577)
- Diodes: https://www.digikey.com/product-detail/en/micro-commercialco/1N4148W-TP/1N4148WTPMSCT-ND/717311 (https://www.digikey.com/product-detail/en/micro-commercial-co/1N4148W-TP/1N4148WTPMSCT-ND/717311)
- Button: https://www.digikey.com/product-detail/en/e-switch/TL3342F160QG-TR/EG2531CT-ND/379004 (https://www.digikey.com/product-detail/en/e-switch/TL3342F160QG-TR/EG2531CT-ND/379004)
- Mini USB Connector: https://www.digikey.com/product-detail/en/hirose-electricco-ltd/UX60SC-MB-5S8/H11589CT-ND/1949225 (https://www.digikey.com/product-detail/en/hirose-electric-co-ltd/UX60SC-MB-5S8/H11589CT-ND/1949225)

Other good places to get electronic components include Mouser (http://mouser.com/) and element14. (http://element14.com/)

Good luck and have fun building your own PCBs!

Releases (https://github.com/ruiqimao/keyboard-pcb-guide/releases)

No releases published

Packages (https://github.com/users/ruiqimao/packages?repo_name=keyboard-pcb-guide)

No packages published

Contributors 2 (https://github.com/ruiqimao/keyboard-pcb-guide/graphs/contributors)

ruiqimao Ruiqi Mao (https://github.com/ruiqimao)

felixphew Felix (https://github.com/felixphew)

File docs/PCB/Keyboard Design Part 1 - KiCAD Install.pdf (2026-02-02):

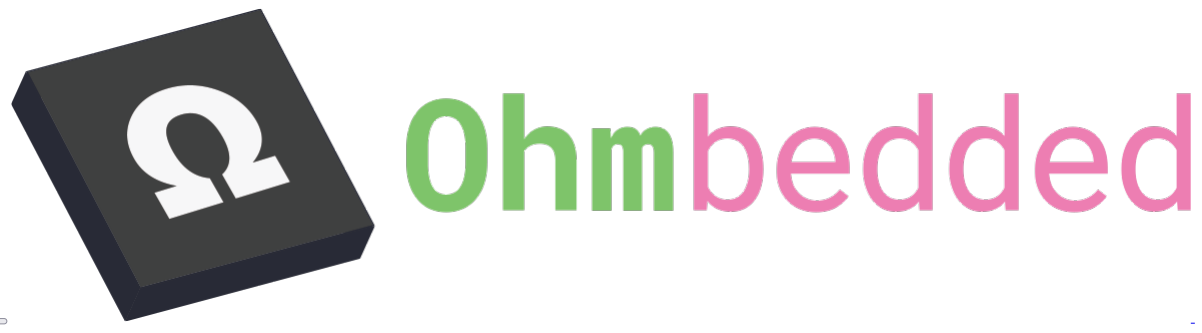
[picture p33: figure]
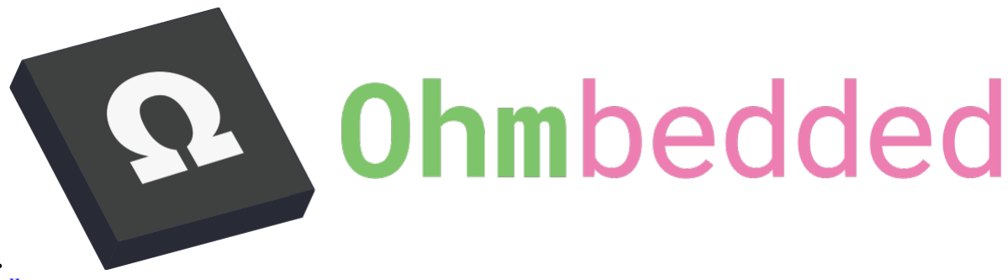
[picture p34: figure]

•
- Home (https://ohmbedded.com/)
- More

•

Recent articles

Tags

- No tags found :(

Toggle light/dark mode

nRF7000 - Wi-Fi Scan w/ the 7002-EK + nRF58240

2 years ago (https://ohmbedded.com/nrf7000-wi-fi-scan-w-the-7002-ek/)

zperf - Evaluating th

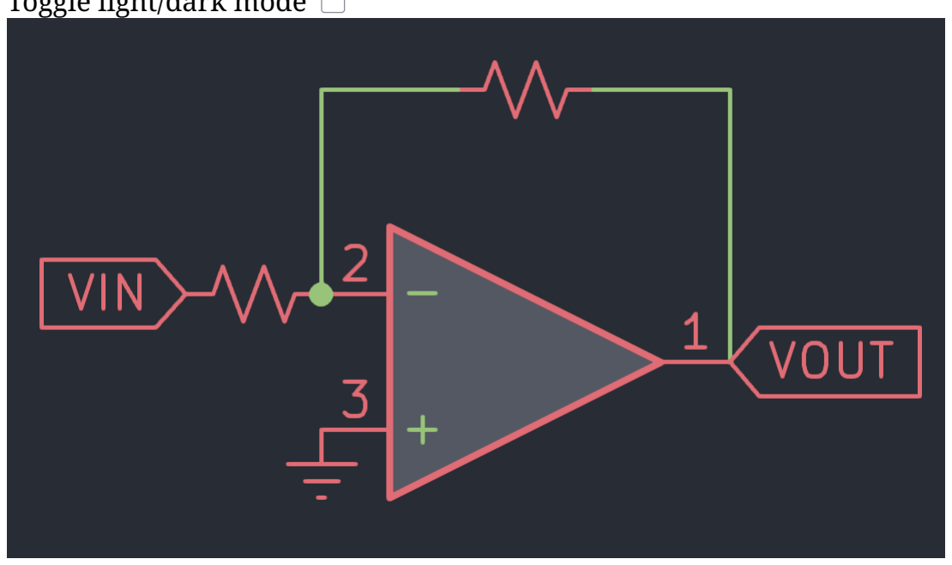
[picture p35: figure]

## Keyboard Design Part 1 - KiCAD Install

Mar 20, 2023

Welcome to the first part in a series on mechanical keyboard design.

KiCAD is the hobbyist's greatest weapon in creating bespoke electronics. It is a completely free and open-source electronic design automation (EDA) suite. It is available on most commonly used platforms including Windows, Linux, and macOS.

The process of creating a PCB design in KiCAD involves first creating a schematic to describe the abstract electronic parts of a device (i.e. the individual resistors, capacitors, integrated circuits, etc.) to create a list of "nets" or connections between parts.

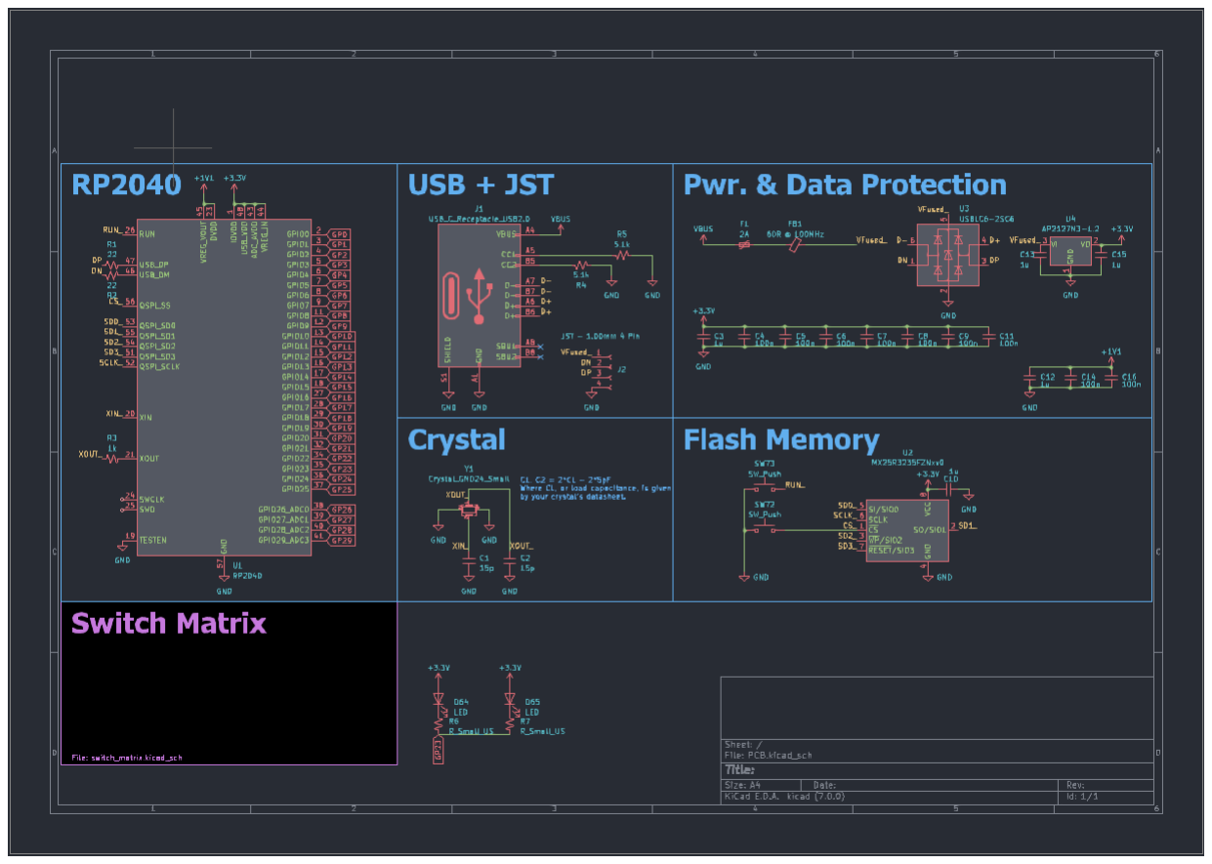
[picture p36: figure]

Here is an example of a schematic for a keyboard using an RP2040 microcontroller. Throughout the series you will learn what every part of the above schematic means.

This "netlist" is then used to create the physical layout of a PCB.

The above may sound a bit abstract. Let's dive into the nitty gritty of PCB design by setting up a stellar KiCAD configuration for mechanical keyboard electronics design.

Subscribe

Keyboard Design Part 1 - KiCAD Install | https://ohmbedded.com/keyboard-design-part-1-kicad-install/
1 of 5 | 1/25/26, 17:12

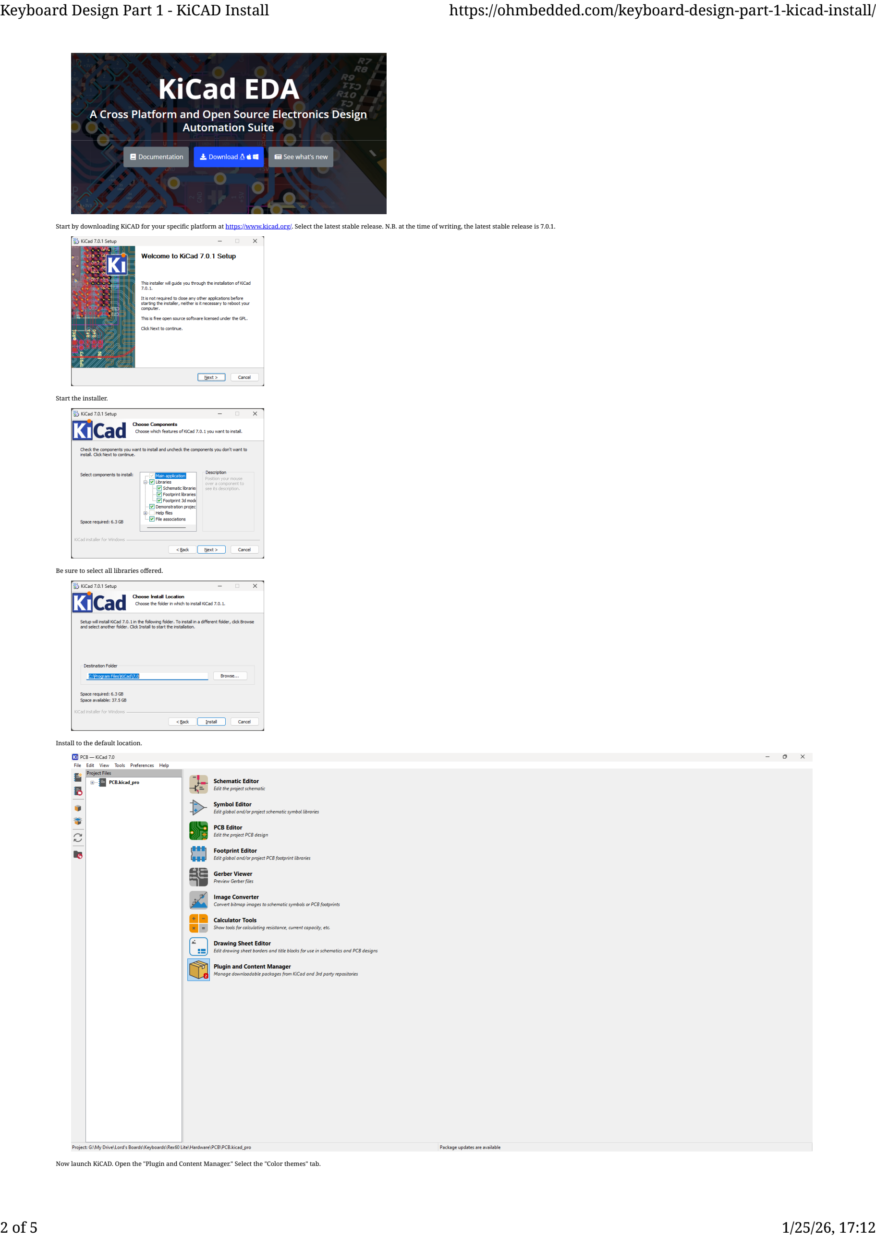
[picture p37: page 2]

Start by downloading KiCAD for your specific platform at https://www.kicad.org/. (https://www.kicad.org/?ref=ohmbedded.com) Select the latest stable release. N.B. at the time of writing, the latest stable release is 7.0.1.

Start the installer.

Be sure to select all libraries offered.

Install to the default location.

Now launch KiCAD. Open the "Plugin and Content Manager." Select the "Color themes" tab.

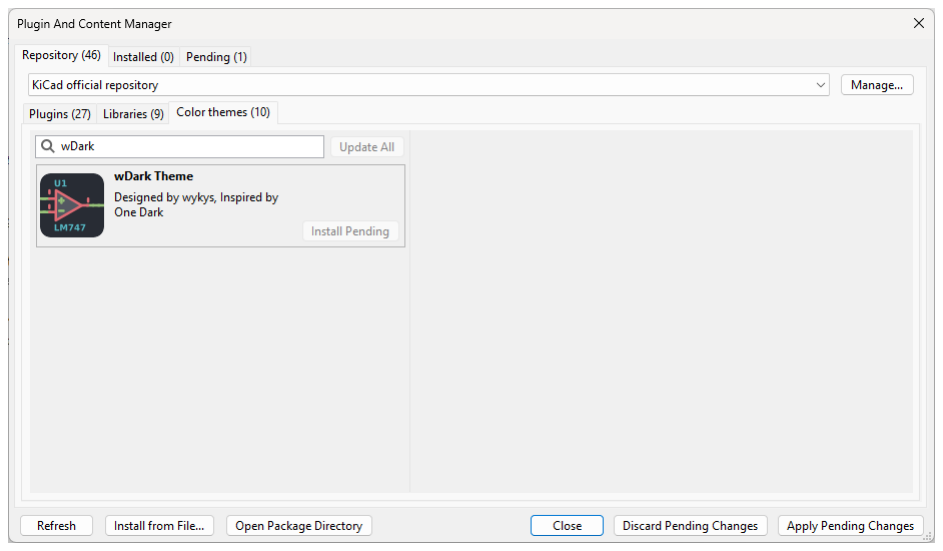
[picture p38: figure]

N.B. packages will not install until you have clicked "Apply Pending Changes." Select the packages you want to install first.
Select the "wDark Theme" and click "Install" to save your eyesight.

Next, click the "Manage..." button. You will be greeted with a dialogue that will become familiar once working with symbol/footprint tables.

For now, copy and paste the following link to add the kicad-jlcpcb-tools plugin repository by Bouni. (https://github.com/Bouni?ref=ohmbedded.com)

https://raw.githubusercontent.com/Bouni/bouni-kicad-repository/main/repository.json

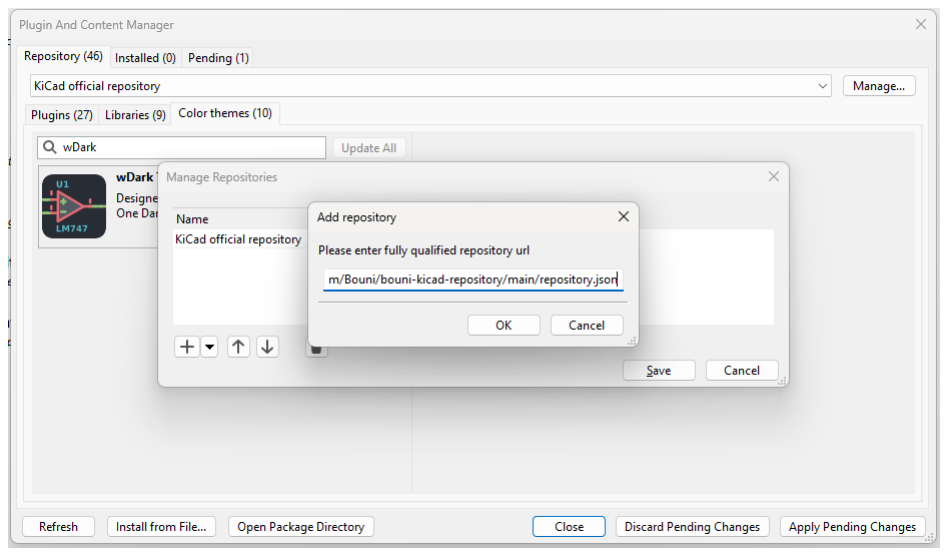
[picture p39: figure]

Click "Apply Pending Changes," select the respository dropdown to switch to Bouni's repository.

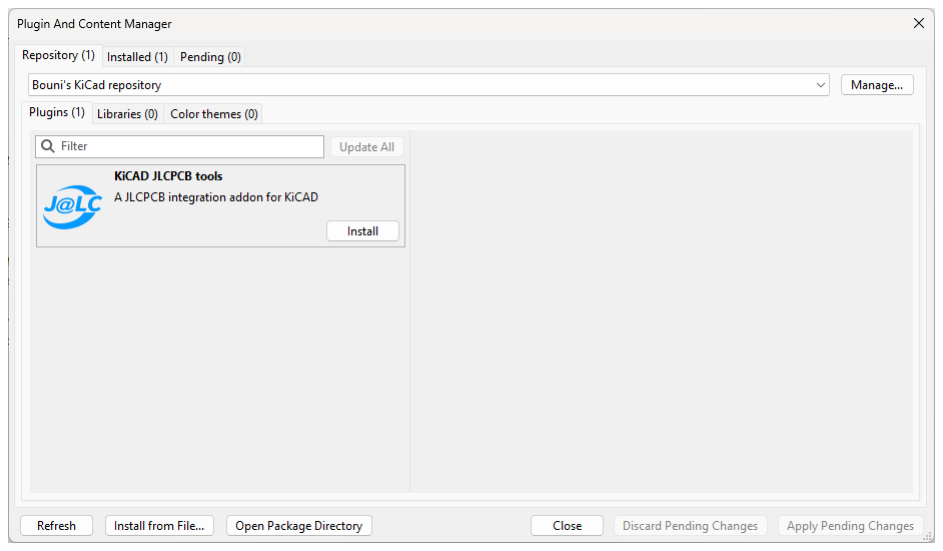
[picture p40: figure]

Install KiCAD JLCPCB tools and click "Apply Pending Changes."

The final step is to install a very useful KiCAD schematic symbol and footprint library specific to mechanical keyboard development.

Marbastlib is a mechanical keyboard switch/general part library that I have used for almost every mechanical keyboard I have designed.

GitHub - ebastler/marbastlib: A library collecting MX and Choc style footprints, as well as various other parts used to design custom keyboards
A library collecting MX and Choc style footprints, as well as various other parts used to design custom keyboards - GitHub - ebastler/marbastlib: A library collecting MX and Choc style footprints,…

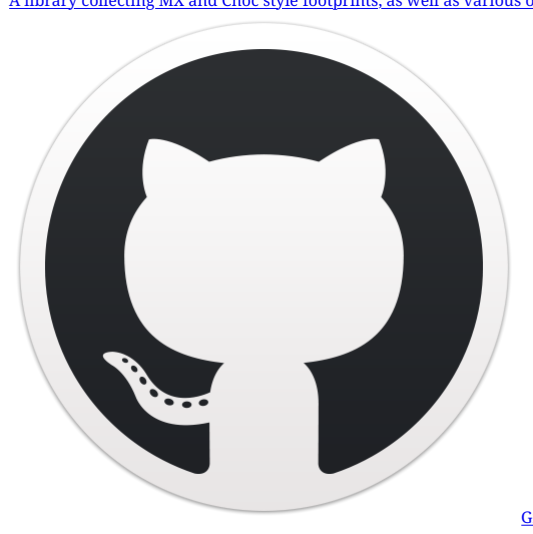
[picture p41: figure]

GitHubebastler (https://github.com/ebastler/marbastlib?ref=ohmbedded.com)

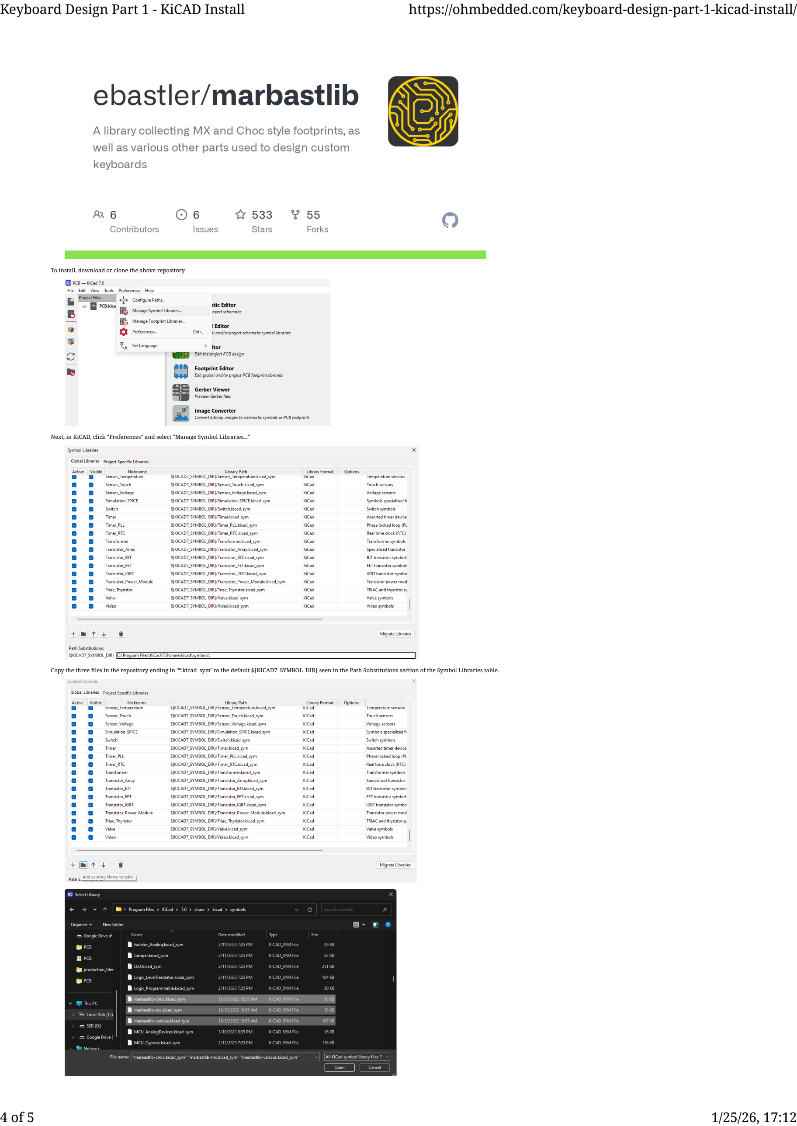
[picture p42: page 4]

To install, download or clone the above repository.

Next, in KiCAD, click "Preferences" and select "Manage Symbol Libraries..."

Copy the three files in the repository ending in "*.kicad_sym" to the default ${KICAD7_SYMBOL_DIR} seen in the Path Substitutions section of the Symbol Libraries table.

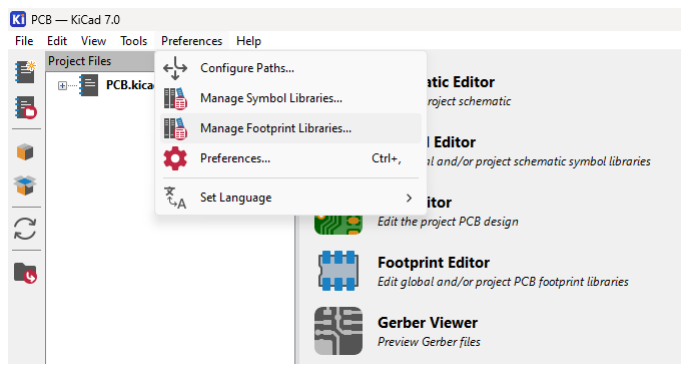
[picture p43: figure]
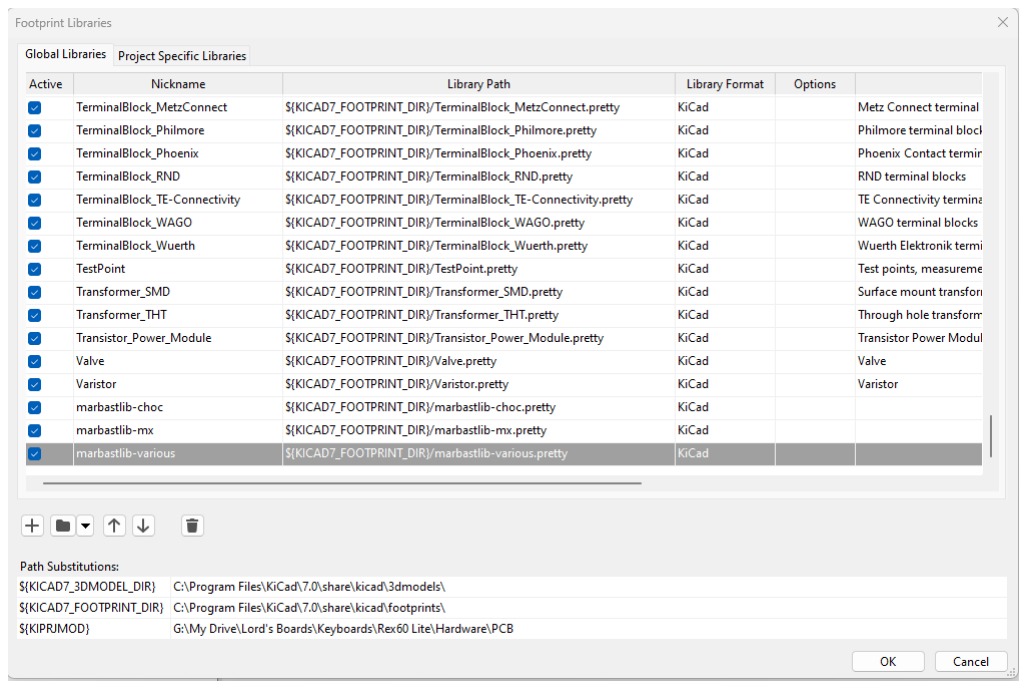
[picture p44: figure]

Subscribe to our newsletter

Get the latest posts delivered right to your inbox.

Your email address Your emai address

Subscribe

Now check your inbox and click the link to confirm your subscription.

Please enter a valid email address

Oops! There was an error sending the email, please try later.

Helmut Lord (https://ohmbedded.com/author/helmut/)

Recommended for you

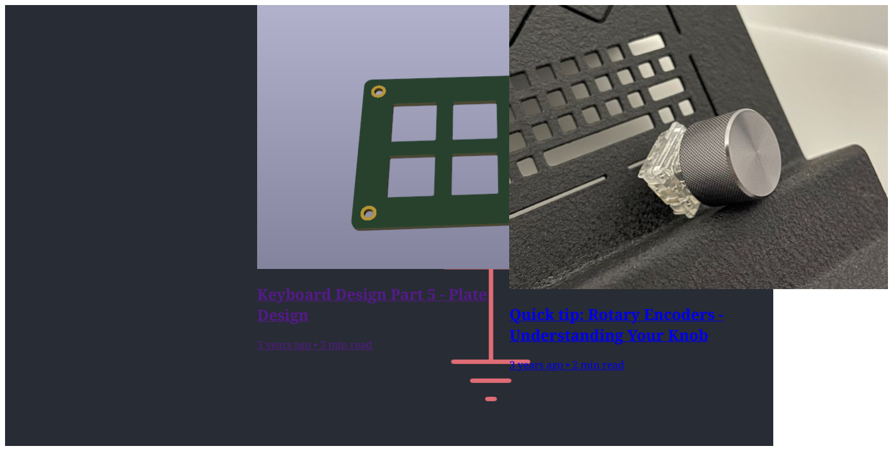
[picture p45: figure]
Keyboard Design Part 5 - Plate Design; 3 years ago • 3 min read; Quick tip: Rotary Encoders - Understanding Your Knob; 3 years ago • 2 min read

- Sign up (https://ohmbedded.com/keyboard-design-part-1-kicad-install/#/portal/)

Ohmbedded © 2026 • Published with Ghost (https://ghost.org/)

JavaScript license information (https://ohmbedded.com/assets/html/javascript.html?v=2e02768879)

Next click the "Add existing library to table" button and select the three files you just added. Three new rows should be added to your Symbol Libraries table.

Next, open the "Manage Footprint Libraries..." dialogue from the Preferences dropdown. Much the same process here. Find the ${KICAD7_FOOTPRINT_DIR}, copy over the folders this time, and add them to the table. Generally, KiCAD footprint library folders end with "*.pretty" Optionally, copy the "3d" folder to the ${KICAD7_3DMODEL_DIR}.

You have now completed setup of KiCAD for mechanical keyboard design! In the next tutorial, we will take a look at the basics of keyboard electronics.

Click here for part 2! (https://ohmbedded.com/keyboard-design-part-2-pro-micro-based-designs/)

For more information and to ask keyboard specific or general electronics questions join our Discord!

Join the Ohmbedded Discord Server!
Check out the Ohmbedded community on Discord - hang out with 1 other members and enjoy free voice and text chat. Discord (https://discord.gg/Q8EbKyAjWN?ref=ohmbedded.com)

Tags

### Quick tip: Decoupling Capacitors

3 years ago • 4 min read (https://ohmbedded.com/quick-tip-decoupling-capacitors-2/)

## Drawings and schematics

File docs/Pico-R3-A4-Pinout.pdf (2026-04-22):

# Raspberry Pi Pico Pinout

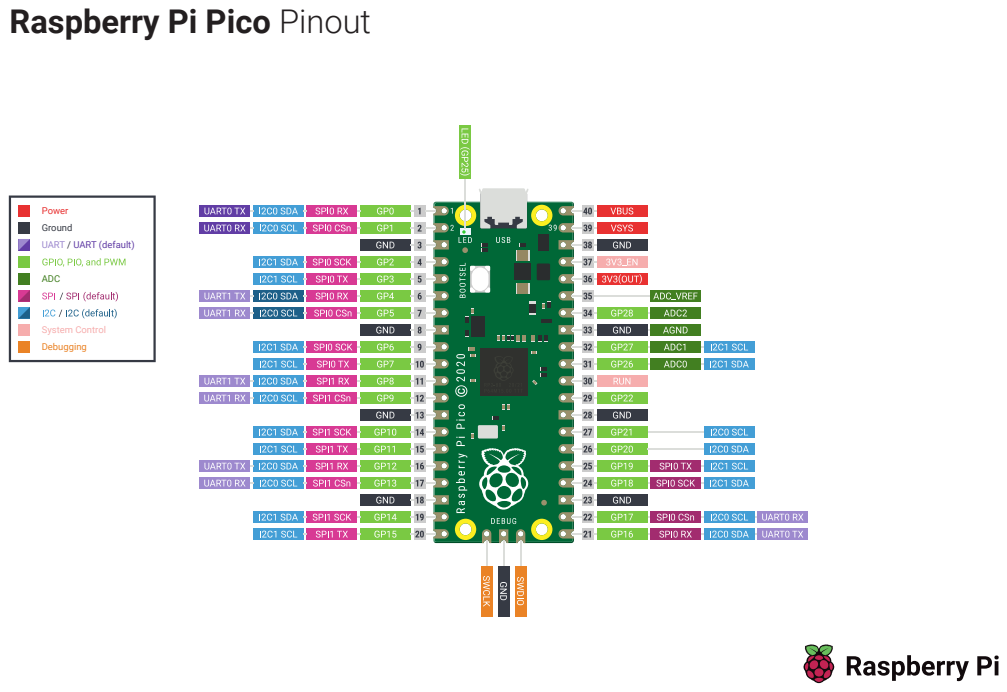
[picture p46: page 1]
System Control Debugging; ADC

Power
Ground
UART / UART (default)

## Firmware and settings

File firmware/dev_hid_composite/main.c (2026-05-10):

#include <stdlib.h>
#include <stdio.h>
#include <string.h>

#define SSD1306_IMPL

#include "ssd1306.h"
#include "hardware/i2c.h"
#include "pico/stdlib.h"
#include "hardware/pio.h"
#include "hardware/clocks.h"
#include "ws2812.pio.h"
#include "hardware/adc.h"

#include "bsp/board_api.h"
#include "tusb.h"

#include "usb_descriptors.h"

#include "hardware/flash.h"
#include "hardware/sync.h"

// Initilisation du port des PINs pour l'OLED
#define I2C_PORT i2c0
#define SDA_PIN 8
#define SCL_PIN 9

// Choix de la taille de la matrice de touche
#define Nb_col 4
#define Nb_ligne 5
#define NUM_PIXELS 20

// Choix du PIN pour l'envoi du bus de LEDs
#define WS2812_PIN 22
#define IS_RGBW false

// Définition du nombre de mode pour motif de LEDs
#define NB_MODE 4 

// Nous choisissons une zone à la fin de la flash (ex: 1.5Mo après le début)
#define FLASH_TARGET_OFFSET (1536 * 1024)
const uint8_t *flash_contents = (const uint8_t *) (XIP_BASE + FLASH_TARGET_OFFSET);


#define FLASH_MAGIC 0xAB
#define FLASH_VERSION __TIME__  // Change à chaque compilation

void __not_in_flash_func(save_mapping_to_flash)(uint8_t keys[Nb_ligne][Nb_col], uint8_t hues[20]) {
    uint32_t ints = save_and_disable_interrupts();
    
    // Nous effacons le secteur (nécessaire avant l'écrire)
    flash_range_erase(FLASH_TARGET_OFFSET, FLASH_SECTOR_SIZE);
    
    uint8_t buffer[FLASH_PAGE_SIZE] = {0};
    buffer[0] = FLASH_MAGIC;  // Octet de contrôle

    // Nous copions le temps __TIME__ 
    memcpy(buffer + 1, __TIME__, 8);  // 8 caractères ex: "14:32:05"

    // Nous copions les 20 octets de touches à partir de l'index 9 - Le mapping de touche 
    memcpy(buffer + 9, keys, 20); 
    
    // Nous copions les 20 octets de couleurs à partir de l'index 29 - La couleur des LEDs
    memcpy(buffer + 29, hues, 20);
    
    // Nous écrivons le tout d'un coup
    flash_range_program(FLASH_TARGET_OFFSET, buffer, FLASH_PAGE_SIZE);
    
    restore_interrupts(ints);
}

//--------------------------------------------------------------------+
// MACRO CONSTANT TYPEDEF PROTYPES
//--------------------------------------------------------------------+

/* Blink pattern
 * - 250 ms  : device not mounted
 * - 1000 ms : device mounted
 * - 2500 ms : device is suspended
 */
enum  {
  BLINK_NOT_MOUNTED = 250,
  BLINK_MOUNTED = 1000,
  BLINK_SUSPENDED = 2500,
};

static uint32_t blink_interval_ms = BLINK_NOT_MOUNTED;
const uint32_t blink_led = 500; 
const uint32_t blink_RGB = 30; 

// Variable globale pour stocker le timestamp de l'appui
volatile uint32_t last_key_press_time = 0;
volatile uint32_t last_latency_ms = 0; 

// --------------- Appel des fonctions ----------------

void pico_init(); 

void hid_task(void);

void led_blinking_task(void);

uint32_t hsv_to_urgb(uint8_t h, uint8_t s, uint8_t v);
int RGB(PIO pio, uint sm, uint len, uint t);

void pattern_wave(PIO pio, uint sm, uint len, uint t, uint s);
void pattern_rainbow(PIO pio, uint sm, uint len, uint t, uint s);
void pattern_reaction(PIO pio, uint sm, uint len, uint t, uint s);
void pattern_custom_individual(PIO pio, uint sm);

void update_oled_display();

void tud_cdc_line_state_cb(uint8_t itf, bool dtr, bool rts);
void tud_cdc_rx_cb(uint8_t itf);

//-------------------------------------------------------------------+
// KEYBOARD MATRIX MAPPING
//-------------------------------------------------------------------+

// Définition des Ports de GPIO pour la mapping des touches
const uint row_pins[] = {15,
                        14,
                        13,
                        12,
                        11};
const uint col_pins[] = {18,19,20,21};

// Mapping des touches par défaut 
uint8_t hid_keys[Nb_ligne][Nb_col] = {
    {HID_KEY_A,             HID_KEY_B,  HID_KEY_G,  HID_KEY_H},
    {HID_KEY_C,             HID_KEY_D,  HID_KEY_I,  HID_KEY_J},
    {HID_KEY_Q,             HID_KEY_Z,  HID_KEY_K,  HID_KEY_L},
    {HID_KEY_SHIFT_LEFT,    HID_KEY_N,  HID_KEY_O,  HID_KEY_P},
    {HID_KEY_CONTROL_LEFT,  HID_KEY_R,  HID_KEY_S,  HID_KEY_T}
};

// Matrice pour la détection de touche & temps d'appui
volatile int keys_pressed[Nb_ligne][Nb_col] = {
    {0,0,0,0},
    {0,0,0,0},
    {0,0,0,0},
    {0,0,0,0},
    {0,0,0,0},
};

// Matrice pour savoir quelle touche envoyer à l'HID
int keys_to_send[Nb_ligne][Nb_col] = {
    {0,0,0,0},
    {0,0,0,0},
    {0,0,0,0},
    {0,0,0,0},
    {0,0,0,0},
};

// Matrice pour le statut d'appui long d'une touche ou non ( Si 1 -> Appui long )
int keys_pressed_long_time[Nb_ligne][Nb_col] = {
    {0,0,0,0},
    {0,0,0,0},
    {0,0,0,0},
    {0,0,0,0},
    {0,0,0,0},
};

//-------------------------------------------------------------------+
// KEYBOARD MATRIX LEDs
//-------------------------------------------------------------------+

//----------------- Matrices  pour le mode "REACTION" des LEDS ----------------------
// Permet de connaître l'emplacement de la LED actuelle et de sa durée de vie
volatile int led_life[Nb_ligne][Nb_col] = {
    {0,0,0,0},
    {0,0,0,0},
    {0,0,0,0},
    {0,0,0,0},
    {0,0,0,0},
};

// Permet de connaître l'emplacement de la prochaine LED et de sa durée de vie restante
volatile int led_life_next[Nb_ligne][Nb_col] = {
    {0,0,0,0},
    {0,0,0,0},
    {0,0,0,0},
    {0,0,0,0},
    {0,0,0,0},
};

volatile int potar = 0;
volatile int keys_pressed_potar = 0;
volatile int keys_pressed_potar_long_time = 0;

int Nb_temps_long = 500; //Temps avant d'être dans l'état : Appuie long 
int Compteur_temps_long = 5; //Compteur une fois dans l'état : Appuie long

uint8_t led_hues[20] = {0}; // Stocke la teinte de chaque LED (0-255)

bool repeating_timer_callback(struct repeating_timer *t) {
  //------------ Lecture de l'appui du Potar --------------
  if ((gpio_get(17)==0)&&(keys_pressed_potar == 0)){ // Détection d'un appui nouveau
    potar = (potar + 1)%NB_MODE;
    if(keys_pressed_potar_long_time == 1){
      keys_pressed_potar = Compteur_temps_long;
    } else {
      keys_pressed_potar = 1;
    }
  } else if ( gpio_get(17)==0 && keys_pressed_potar!=0 && keys_pressed_potar_long_time==0 ){ // Détection d'un appui en temps court
    keys_pressed_potar+=1;
    if(keys_pressed_potar>=Nb_temps_long){
      keys_pressed_potar=0;
      keys_pressed_potar_long_time=1;
    }
  } else if (gpio_get(17)==0 &&keys_pressed_potar_long_time==1) { // Détection d'un appui en temps long
    keys_pressed_potar=(keys_pressed_potar+Compteur_temps_long)%Nb_temps_long;
  } else {  // Pas d'appui
      keys_pressed_potar = 0;
      keys_pressed_potar_long_time = 0;
  }

  //------------ Ensemble de colonnes mis à 0 avant lecture de la matrice --------------
  for(int init = 0; init < Nb_col; init++){
    gpio_put(col_pins[init], 0);
  }

  //------------ Détection de l'appui de touche sur l'ensemble de la matrice --------------
  for(int col = 0; col < Nb_col; col++){
    gpio_put(col_pins[col], 1); // Colonne à un 1 logique pour détecter l'appui d'une touche
    busy_wait_us(2); // Temps de pause pour la stabilisation électriques des GPIOs de colonnes

    for (int row = 0; row < Nb_ligne; row++) {
      if (gpio_get(row_pins[row])&&(keys_pressed[row][col]==0)) { // Détection d'un appui nouveau
        keys_to_send[row][col] = 1 ; 
        led_life[row][col] = 10 ;
        last_key_press_time = board_millis();  // début du timestamp 
        if(keys_pressed_long_time[row][col]==1){
          keys_pressed[row][col]=Compteur_temps_long;
        } else {
          keys_pressed[row][col]=1;
        }
      } else if(gpio_get(row_pins[row])&&(keys_pressed[row][col]!=0)&&(keys_pressed_long_time[row][col]==0)) { // Détection d'un appui en temps court
        keys_pressed[row][col]+=1;
        if((hid_keys[row][col]==HID_KEY_CONTROL_RIGHT || hid_keys[row][col]==HID_KEY_SHIFT_LEFT) && keys_pressed[row][col]>=Nb_temps_long/10){
          keys_pressed[row][col]=0;
          keys_pressed_long_time[row][col]=1;
        } else if(keys_pressed[row][col]>=Nb_temps_long){
          keys_pressed[row][col]=0;
          keys_pressed_long_time[row][col]= 1 ;
        }
      } else if(gpio_get(row_pins[row])&&keys_pressed_long_time[row][col]==1) { // Détection d'un appui en temps long
        if(hid_keys[row][col]==HID_KEY_CONTROL_RIGHT || hid_keys[row][col]==HID_KEY_SHIFT_LEFT){
          keys_pressed[row][col] = 1 ;
          keys_to_send[row][col] = 1 ;
        } else {
          keys_pressed[row][col]=(keys_pressed[row][col]+Compteur_temps_long)%Nb_temps_long;
        }
      } else { // Pas d'appui
        if (keys_pressed[row][col] != 0) {
          // La touche vient d'être relâchée → on calcule la latence
          last_latency_ms = board_millis() - last_key_press_time;
        }
        keys_to_send[row][col] = 0 ; 
        keys_pressed[row][col]= 0 ;
        keys_pressed_long_time[row][col]= 0 ;
      }
    } 
    gpio_put(col_pins[col], 0);
  }
  return true; 
}

static inline void put_pixel(PIO pio, uint sm, uint32_t pixel_grb) {
    pio_sm_put_blocking(pio, sm, pixel_grb << 8u);
}

static inline uint32_t urgb_u32(uint8_t r, uint8_t g, uint8_t b) {
    return ( ((uint32_t) (r) << 8) | ((uint32_t) (g) << 16) | (uint32_t) (b) );
}

// Invoked when cdc when line state changed e.g connected/disconnected
void tud_cdc_line_state_cb(uint8_t itf, bool dtr, bool rts) {
    (void) itf;
    (void) rts;

    // Si DTR est true, le PC vient d'ouvrir le port COM
    if ( dtr ) {
        // Optionnel : Peut servir à montrer visuellement si l'ouverture du port est fonctionnel
    }
}

// Cette fonction est appelée dès que des données arrivent
void tud_cdc_rx_cb(uint8_t itf) {
    (void) itf;
}

/*------------- MAIN -------------*/

int main(void)
{
   // --------------- Initilisation des ports GPIOs, OLED et autres -----------------
  board_init();
  stdio_init_all();
  pico_init(); 

   // --------------- Lecture de la ram au démarrage / Lecture par défaut au nouveau BOOT --------------
  if (flash_contents[0] == FLASH_MAGIC && memcmp(flash_contents + 1, __TIME__, 8) == 0) {
    memcpy(hid_keys, flash_contents + 9, 20); // Copie du mapping de touches
    memcpy(led_hues, flash_contents + 29, 20); // Copie du mapping de LEDs
  } 
  // --------------- Lecture de l'écran OLED ---------------
  update_oled_display();

  // --------------- Initilisation de la fonction callback ( Lecture de la matrice périodiquement avec T = 1ms ) ------------
  struct repeating_timer timer;
  add_repeating_timer_us(-1000, repeating_timer_callback, NULL, &timer);

   // --------------- Variable nécessaire à l'actualisation de l'écran OLED ------------------
  int last_known_potar = -1;
  int compteur_actu = 0;

  // ---------------- Initialisation de Tiny usb -----------------
  tud_init(BOARD_TUD_RHPORT);
  if (board_init_after_tusb) {
    board_init_after_tusb();
  }

  PIO pio;
  uint sm;
  uint offset;

  // --------------- Vérification de la disponibilité de PIO / SM et Offset -----------------
  bool success = pio_claim_free_sm_and_add_program_for_gpio_range(&ws2812_program, &pio, &sm, &offset, WS2812_PIN, 1, true);
  hard_assert(success);

  // --------------- Initialisation des LEDs sur GPIO, SM ( State Machine ) à 800khz ---------------
  ws2812_program_init(pio, sm, offset, WS2812_PIN, 800000, IS_RGBW);

  uint t = 0;

  // --------------- Gestion du CDC ---------------
  static uint8_t cdc_buffer[20];
  static uint8_t cdc_idx = 0;
  static bool cdc_connected = false;

  while (1)
  {
    tud_task();
    led_blinking_task();

    // --------------- Actualisation de l'écran OLED tous les 100000 cycles d'incrémentation de compteur_actu -----------
    compteur_actu++;
    if (compteur_actu > 100000) {
      update_oled_display();
      compteur_actu = 0;
    }

    int incr = RGB(pio, sm, NUM_PIXELS, t);

     // --------------- Actualisation de l'écran OLED à chaque changement de mode de LEDs -------------
    if (potar != last_known_potar) {
      update_oled_display();
      last_known_potar = potar;
    }

    if (incr == 1) {
      t = (t + 1);
      incr = 0;
    }

    hid_task();

    // Reset du buffer si déconnexion/reconnexion
    bool currently_connected = tud_cdc_connected();
    if (!currently_connected && cdc_connected) {
        cdc_idx = 0;
    }
    cdc_connected = currently_connected;

    // --------------- Gestion du CDC (40 octets : 20 touches + 20 couleurs) ---------------
    static uint8_t cdc_buffer[40]; 

    
    while (tud_cdc_available()) {
        uint8_t byte = tud_cdc_read_char();

        // Permet d'ignorer les index hors limites
        if (cdc_idx >= 40) {
            cdc_idx = 0;
        }

        cdc_buffer[cdc_idx++] = byte;

        if (cdc_idx == 40) {
            // Nous récupérons les touches (20 premiers octets)
            memcpy(hid_keys, cdc_buffer, 20);
            
            // Nous récupérons les couleurs des LEDs (20 octets suivants)
            memcpy(led_hues, cdc_buffer + 20, 20);

            // Sauvegarde des touches et couleurs des LEDs dans la flash
            save_mapping_to_flash(hid_keys, led_hues);

            // Feedback série de debug - à lire dans le terminal 
            char debug[64];
            sprintf(debug, "OK! Keys received.\nLED[0] Hue: %02X\n\nKEYS[0,0] : %02X", led_hues[0], hid_keys[0][0]);
            tud_cdc_write(debug, strlen(debug));
            tud_cdc_write_flush();

            cdc_idx = 0; // Prêt pour le prochain envoi
        }
    }
  }
  pio_remove_program_and_unclaim_sm(&ws2812_program, pio, sm, offset);
}

//--------------------------------------------------------------------+
// Device callbacks
//--------------------------------------------------------------------+

// Invoked when device is mounted
void tud_mount_cb(void)
{
  blink_interval_ms = BLINK_MOUNTED;
}

// Invoked when device is unmounted
void tud_umount_cb(void)
{
  blink_interval_ms = BLINK_NOT_MOUNTED;
}

// Invoked when usb bus is suspended
// remote_wakeup_en : if host allow us  to perform remote wakeup
// Within 7ms, device must draw an average of current less than 2.5 mA from bus
void tud_suspend_cb(bool remote_wakeup_en)
{
  (void) remote_wakeup_en;
  blink_interval_ms = BLINK_SUSPENDED;
}

// Invoked when usb bus is resumed
void tud_resume_cb(void)
{
  blink_interval_ms = tud_mounted() ? BLINK_MOUNTED : BLINK_NOT_MOUNTED;
}

//--------------------------------------------------------------------+
// USB HID
//--------------------------------------------------------------------+
static void send_hid_report(uint8_t report_id)
{
  // skip if hid is not ready yet
  if ( !tud_hid_ready() ) return;

  switch(report_id)
  {
      case REPORT_ID_KEYBOARD:
  {
      static bool has_keyboard_key = false;
      uint8_t keycode[6] = { 0 };
      uint8_t indice = 0;
      for (int col = 0; col < Nb_col; col++){
          for (int row = 0; row < Nb_ligne; row++) {
              if(keys_to_send[row][col]==1 && indice != 6){ 
                  // Debug : affiche ce que nous allons envoyer
                  char debug[32];
                  sprintf(debug, "sending [%d][%d]=%02X\n", row, col, hid_keys[row][col]);
                  tud_cdc_write(debug, strlen(debug));
                  tud_cdc_write_flush();
                  
                  keycode[indice] = hid_keys[row][col];
                  keys_to_send[row][col] = 0;
                  indice++;
              }
          }
      }
      tud_hid_keyboard_report(REPORT_ID_KEYBOARD, 0, keycode);
      has_keyboard_key = false;
  }
    break;
    default: break;
  }

}

void hid_task(void)
{
  const uint32_t interval_ms = 10; // durée entre deux déclenchement 
  static uint32_t start_ms = 0; // debut du compteur 

  if ( board_millis() - start_ms < interval_ms)// nous sortons de la fonction
    {return;} 
  start_ms += interval_ms; //mise à jour du compteur
  
  send_hid_report(REPORT_ID_KEYBOARD);
  
}


// Invoked when received GET_REPORT control request
// Application must fill buffer report's content and return its length.
// Return zero will cause the stack to STALL request
uint16_t tud_hid_get_report_cb(uint8_t instance, uint8_t report_id, hid_report_type_t report_type, uint8_t* buffer, uint16_t reqlen)
{
  // TODO not Implemented
  (void) instance;
  (void) report_id;
  (void) report_type;
  (void) buffer;
  (void) reqlen;
  return 0;
}

// Invoked when received SET_REPORT control request or
// received data on OUT endpoint ( Report ID = 0, Type = 0 )
void tud_hid_set_report_cb(uint8_t instance, uint8_t report_id, hid_report_type_t report_type, uint8_t const* buffer, uint16_t bufsize)
{
  (void) instance;
  if (report_type == HID_REPORT_TYPE_OUTPUT)
  {
    // Set keyboard LED e.g Capslock, Numlock etc...
    if (report_id == REPORT_ID_KEYBOARD)
    {
      // bufsize should be (at least) 1
      if ( bufsize < 1 ) return;
      uint8_t const kbd_leds = buffer[0];
      if (kbd_leds & KEYBOARD_LED_CAPSLOCK)
      {
        // Capslock On: disable blink, turn led on
        blink_interval_ms = 0;
        board_led_write(true);
      }else
      {
        // Caplocks Off: back to normal blink
        board_led_write(false);
        blink_interval_ms = BLINK_MOUNTED;
      }
    }
  }
}

//--------------------------------------------------------------------+
// BLINKING TASK
//--------------------------------------------------------------------+
void led_blinking_task(void)
{
  static uint32_t start_ms = 0;
  static bool led_state = false;

  // blink is disabled
  if (!blink_interval_ms) return;

  // Blink every interval ms
  if ( board_millis() - start_ms < blink_interval_ms) return; // not enough time
  start_ms += blink_interval_ms;

  board_led_write(led_state);
  led_state = 1 - led_state; // toggle
}

// -------------- Choix du pattern des LEDs et des timings d'affichage ---------------
int RGB(PIO pio, uint sm, uint len, uint t)
{
  int res = 0 ; 
  static uint32_t start_ms = 0;
  static bool led_state = false; 
  // blink is disabled
  if (!blink_led) return res ;

  // Blink every interval ms
  if ( board_millis() - start_ms < blink_RGB) return res ; // not enough time
  start_ms += blink_RGB;

  if (led_state){
    if (potar == 0) {
      pattern_rainbow(pio,sm,len,t, 0);
    } else if(potar == 1) {
      pattern_wave(pio,sm,len,t, 0);
    } else if(potar ==2) {
      pattern_reaction(pio,sm,len,t,0);
    } else { 
      pattern_custom_individual(pio,sm);
    }
    res = 1 ; 
  }
  else {
      res = 0 ; 
  }
  led_state = 1 - led_state; // toggle
  return res ; 
}

// --------------- Pattern réaction de touche et propagation ----------------
void pattern_reaction(PIO pio, uint sm, uint len, uint t, uint s) {
    // Initilisation du prochain tableau
    uint8_t next_life[Nb_ligne][Nb_col];
    
    // Copie de l'état actuel du tableau pour le modifier
    for (int j = 0; j < Nb_ligne; j++) {
        for (int i = 0; i < Nb_col; i++) {
            next_life[j][i] = led_life[j][i];
        }
    }
    // Parcour de l'ensemble du tableau
    for (uint j = 0; j < Nb_ligne; j++) {
        for (uint i = 0; i < Nb_col; i++) {
            if (led_life[j][i] > 0) {
                // 1. Nous affichons les leds du tableau actuel
                put_pixel(pio, sm, urgb_u32(led_life[j][i], 0, 0));

                // 2. Propagation des LEDs (seulement si la LED vient d'être activée)
                if (led_life[j][i] == 10) {
                    if (j > 0 && led_life[j-1][i] == 0)             next_life[j-1][i] = 10; // Propagation vers la gauche
                    if (j < Nb_ligne - 1 && led_life[j+1][i] == 0)  next_life[j+1][i] = 10; // Propagation vers la droite
                    if (i > 0 && led_life[j][i-1] == 0)             next_life[j][i-1] = 10; // Propagation vers le haut
                    if (i < Nb_col - 1 && led_life[j][i+1] == 0)    next_life[j][i+1] = 10; // Propagation vers la bas
                }

                // 3. Exinction progressive des LEDs
                if (next_life[j][i] > 0) {
                    next_life[j][i]--;
                }
            } else {
                put_pixel(pio, sm, 0); // Éteint
            }
        }
    }

    // Mise à jour de la matrice globale
    for (uint j = 0; j < Nb_ligne; j++) {
        for (uint i = 0; i < Nb_col; i++) {
            led_life[j][i] = next_life[j][i];
        }
    }
}

// --------------- Pattern Wave / Snake ----------------
void pattern_wave(PIO pio, uint sm, uint len, uint t, uint s){
    int intensite_max = 50;               // Choix de l'intensité max
    int longueur_wave = len/2;              // Choix de la longueur de la wave 
    int milieu_wave = longueur_wave / 2;  // Obtention du milieu de la wave
    int a ; 
  for(uint i = 0; i< len; i++) {  
    if(s){
      a = i + t ;
    } else {
      a = (len - i ) - t ;
    }
    int x = a % (int)len;
    if (x < 0) x += len; // Replacement de x à la fin des leds si il est négatif
    if (x < longueur_wave){ 
      int distance_centre = abs(x - milieu_wave); // Calcul ditance au centre des LEDs
      int r_g;
      if (distance_centre == 0) { 
          r_g = intensite_max; // Intensité maximale au milieu de la wave
      } else {
          r_g = intensite_max / (2*distance_centre); // Pour faible intensité max
      }
      put_pixel(pio, sm, urgb_u32((uint8_t)r_g, r_g, 0));
    } else { 
      put_pixel(pio, sm, urgb_u32(0, 0, 0));
    }
  }
}
// ---------------- Pattern custom ------------------
void pattern_custom_individual(PIO pio, uint sm) {
    for (uint i = 0; i < 20; i++) {
        // Hue = 0 → éteint directement, pas de conversion HSV
        if (led_hues[i] == 0) {
            put_pixel(pio, sm, urgb_u32(0, 0, 0));
        } else {
            put_pixel(pio, sm, hsv_to_urgb(led_hues[i], 255, 10));
        }
    }
}
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

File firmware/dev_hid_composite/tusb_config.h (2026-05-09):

/*
 * The MIT License (MIT)
 *
 * Copyright (c) 2019 Ha Thach (tinyusb.org)
 *
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
 */

#ifndef _TUSB_CONFIG_H_
#define _TUSB_CONFIG_H_

#ifdef __cplusplus
 extern "C" {
#endif

//--------------------------------------------------------------------+
// Board Specific Configuration
//--------------------------------------------------------------------+

// RHPort number used for device can be defined by board.mk, default to port 0
#ifndef BOARD_TUD_RHPORT
#define BOARD_TUD_RHPORT      0
#endif

// RHPort max operational speed can defined by board.mk
#ifndef BOARD_TUD_MAX_SPEED
#define BOARD_TUD_MAX_SPEED   OPT_MODE_DEFAULT_SPEED
#endif

//--------------------------------------------------------------------
// COMMON CONFIGURATION
//--------------------------------------------------------------------

// defined by compiler flags for flexibility
#ifndef CFG_TUSB_MCU
#error CFG_TUSB_MCU must be defined
#endif

#ifndef CFG_TUSB_OS
#define CFG_TUSB_OS           OPT_OS_NONE
#endif

#ifndef CFG_TUSB_DEBUG
#define CFG_TUSB_DEBUG        0
#endif

// Enable Device stack
#define CFG_TUD_ENABLED       1

// Default is max speed that hardware controller could support with on-chip PHY
#define CFG_TUD_MAX_SPEED     BOARD_TUD_MAX_SPEED

/* USB DMA on some MCUs can only access a specific SRAM region with restriction on alignment.
 * Tinyusb use follows macros to declare transferring memory so that they can be put
 * into those specific section.
 * e.g
 * - CFG_TUSB_MEM SECTION : __attribute__ (( section(".usb_ram") ))
 * - CFG_TUSB_MEM_ALIGN   : __attribute__ ((aligned(4)))
 */
#ifndef CFG_TUSB_MEM_SECTION
#define CFG_TUSB_MEM_SECTION
#endif

#ifndef CFG_TUSB_MEM_ALIGN
#define CFG_TUSB_MEM_ALIGN          __attribute__ ((aligned(4)))
#endif

//--------------------------------------------------------------------
// DEVICE CONFIGURATION
//--------------------------------------------------------------------

#ifndef CFG_TUD_ENDPOINT0_SIZE
#define CFG_TUD_ENDPOINT0_SIZE    64
#endif

//------------- CLASS -------------//
#define CFG_TUD_HID               1
#define CFG_TUD_CDC               1
#define CFG_TUD_CDC_RX_BUFSIZE    64      // Taille du buffer de réception (64 octets suffisent pour tes 20 touches)
#define CFG_TUD_CDC_TX_BUFSIZE    64      // Taille du buffer d'envoi
#define CFG_TUD_CDC_EP_BUFSIZE    64      // Taille du buffer Endpoint (obligatoire aussi)

#define CFG_TUD_MSC               0
#define CFG_TUD_MIDI              0
#define CFG_TUD_VENDOR            0

// HID buffer size Should be sufficient to hold ID (if any) + Data
#define CFG_TUD_HID_EP_BUFSIZE    16

#ifdef __cplusplus
 }
#endif

#endif /* _TUSB_CONFIG_H_ */

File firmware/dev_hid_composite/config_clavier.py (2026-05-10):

import tkinter as tk
from tkinter import messagebox, ttk, colorchooser
import serial
import time
import colorsys
 
# =============================================================================
# CONFIGURATION
# =============================================================================
 
# Port série par défaut — modifiable directement dans l'interface
PORT = 'COM6'
 
# Dictionnaire des touches HID disponibles
# Clé = nom affiché dans l'interface, Valeur = keycode HID USB
HID_KEYS = {
    # Lettres
    "A": 0x04, "B": 0x05, "C": 0x06, "D": 0x07, "E": 0x08, "F": 0x09,
    "G": 0x0A, "H": 0x0B, "I": 0x0C, "J": 0x0D, "K": 0x0E, "L": 0x0F,
    "M": 0x10, "N": 0x11, "O": 0x12, "P": 0x13, "Q": 0x14, "R": 0x15,
    "S": 0x16, "T": 0x17, "U": 0x18, "V": 0x19, "W": 0x1A, "X": 0x1B,
    "Y": 0x1C, "Z": 0x1D,
    # Touches spéciales
    "ENTER":      0x28,
    "ESCAPE":     0x29,
    "BACKSPACE":  0x2A,
    "TAB":        0x2B,
    "SPACE":      0x2C,
    "CAPS_LOCK":  0x39,
    # Modificateurs
    "CTRL_L":     0xE0,  # Contrôle gauche
    "CTRL_R":     0xE4,  # Contrôle droit
    "SHIFT_L":    0xE1,  # Majuscule gauche
    "SHIFT_R":    0xE5,  # Majuscule droite
    "ALT_L":      0xE2,  # Alt gauche
    "ALT_R":      0xE6,  # Alt droit (Alt Gr)
}
 
# =============================================================================
# MAPPING PAR DÉFAUT
# Correspond exactement à la disposition physique du clavier :
#
#  ┌─────────┬─────────┬─────────┬─────────┐
#  │  ESC    │  A      │  B      │  C      │
#  ├─────────┼─────────┼─────────┼─────────┤
#  │  TAB    │  D      │  E      │  F      │
#  ├─────────┼─────────┼─────────┼─────────┤
#  │  CAPS   │  G      │  H      │  I      │
#  ├─────────┼─────────┼─────────┼─────────┤
#  │  SHIFT  │  J      │  K      │  L      │
#  ├─────────┼─────────┼─────────┼─────────┤
#  │  CTRL   │  ALT    │  SPACE  │  ENTER  │
#  └─────────┴─────────┴─────────┴─────────┘
# =============================================================================
DEFAULT_MAPPING = [
    ["ESCAPE",   "A",       "B",     "C"    ],
    ["TAB",      "D",       "E",     "F"    ],
    ["CAPS_LOCK","G",       "H",     "I"    ],
    ["SHIFT_L",  "J",       "K",     "L"    ],
    ["CTRL_L",   "ALT_L",   "SPACE", "ENTER"],
]
 
 
# =============================================================================
# CLASSE PRINCIPALE DE L'INTERFACE
# =============================================================================
class KeyboardConfigurator:
    def __init__(self, root):
        self.root = root
        self.root.title("Pico Keyboard Configurator")
        self.root.geometry("720x820")
        self.root.resizable(False, False)
 
        # ------------------------------------------------------------------
        # SECTION : Connexion série
        # ------------------------------------------------------------------
        port_frame = tk.LabelFrame(root, text=" Connexion ", padx=10, pady=8)
        port_frame.pack(fill="x", padx=15, pady=(12, 4))
 
        tk.Label(port_frame, text="Port COM :").pack(side=tk.LEFT)
        self.port_entry = tk.Entry(port_frame, width=10)
        self.port_entry.insert(0, PORT)
        self.port_entry.pack(side=tk.LEFT, padx=5)
 
        # Indicateur de statut de connexion
        self.status_label = tk.Label(port_frame, text="● Non connecté", fg="red")
        self.status_label.pack(side=tk.LEFT, padx=15)
 
        # ------------------------------------------------------------------
        # SECTION : Mapping des touches (matrice 5x4)
        # ------------------------------------------------------------------
        tk.Label(root, text="MAPPING DES TOUCHES", font=('Arial', 10, 'bold')).pack(pady=(10, 2))
 
        self.key_frame = tk.Frame(root)
        self.key_frame.pack(pady=6)
 
        # Création des menus déroulants pour chaque touche de la matrice
        self.key_vars = []
        for r in range(5):
            row_vars = []
            for c in range(4):
                var = tk.StringVar(root)
                # On initialise avec la valeur du mapping par défaut
                var.set(DEFAULT_MAPPING[r][c])
                cb = ttk.Combobox(
                    self.key_frame,
                    textvariable=var,
                    values=list(HID_KEYS.keys()),
                    width=9,
                    state="readonly"
                )
                cb.grid(row=r, column=c, padx=4, pady=4)
                row_vars.append(var)
            self.key_vars.append(row_vars)
 
        # Bouton pour remettre le mapping par défaut
        tk.Button(
            root, text="↺ Remettre le mapping par défaut",
            command=self.reset_mapping, fg="#555"
        ).pack(pady=(0, 8))
 
        # ------------------------------------------------------------------
        # SECTION : Couleurs des LEDs (mode CUSTOM uniquement)
        # Chaque bouton ouvre un sélecteur de couleur et affiche la teinte choisie
        # ------------------------------------------------------------------
        tk.Label(
            root,
            text="COULEURS DES LEDS — Mode CUSTOM (clic = choisir couleur)",
            font=('Arial', 10, 'bold')
        ).pack(pady=(6, 2))
 
        self.led_frame = tk.Frame(root)
        self.led_frame.pack(pady=6)
 
        # led_hues[i] = teinte HSV (0–255) de la LED i
        self.led_hues = [0] * 20
        self.led_buttons = []
 
        for i in range(20):
            btn = tk.Button(
                self.led_frame,
                text=f"L{i+1:02d}",
                width=6,
                height=2,
                bg="black",
                fg="white",
                relief="raised",
                command=lambda idx=i: self.pick_color(idx)
            )
            btn.grid(row=i // 4, column=i % 4, padx=4, pady=4)
            self.led_buttons.append(btn)
 
        # Boutons pour tout mettre à la même couleur ou tout éteindre
        led_ctrl_frame = tk.Frame(root)
        led_ctrl_frame.pack(pady=(0, 8))
        tk.Button(
            led_ctrl_frame, text="🎨 Tout mettre à la même couleur",
            command=self.fill_all_leds
        ).pack(side=tk.LEFT, padx=6)
        tk.Button(
            led_ctrl_frame, text="⬛ Tout éteindre",
            command=self.clear_all_leds
        ).pack(side=tk.LEFT, padx=6)
 
        # ------------------------------------------------------------------
        # SECTION : Bouton d'envoi principal
        # Envoie 40 octets au Pico : 20 touches + 20 teintes LED
        # ------------------------------------------------------------------
        self.send_btn = tk.Button(
            root,
            text="⚡  FLASHER LA CONFIG  (40 octets → Pico)",
            command=self.send_all,
            bg="#2196F3",
            fg="white",
            font=('Arial', 12, 'bold'),
            height=2,
            width=36,
            relief="raised"
        )
        self.send_btn.pack(pady=12)
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

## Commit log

2026-02-02 Premier commit, mise en place de l'arborescence
    [keycaps_arrondi.stl]
2026-02-02 Add SDK link for Raspberry Pi Pico
    Added a link to the Raspberry Pi Pico SDK in the README.
2026-02-09 Seance du 02/02
    [keycaps_plat.stl]
2026-03-10 Script fonctionnel avec 6 boutons sur la breadboard
    [raspberrypi-swd.cfg]
2026-04-22 Le clavier et les leds fonctionnent ensemble, il faut maintenant faire des motifs
    [pio_onewire.fzz, raspberrypi-swd.cfg]
2026-04-22 Motifs Wave sur les leds
    [Cherry_MX_Keycap_v2.stl]
2026-05-06 Modification du git ignore et suppression des fichies inutiles
2026-05-06 Suppression des fichiers inutiles
    [Keycap.stl, keycaps_arrondi.stl, keycaps_plat.stl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]
2026-05-07 mise à jour gitignore et ajout de la case au projet
    [Case.stl]
2026-05-08 Ajustements de valeurs dans le main et ajout d'un graphique pour le rapport
2026-05-08 Ajout des fichiers Kicad
2026-05-09 Ajout personalition de touche via programme Python
